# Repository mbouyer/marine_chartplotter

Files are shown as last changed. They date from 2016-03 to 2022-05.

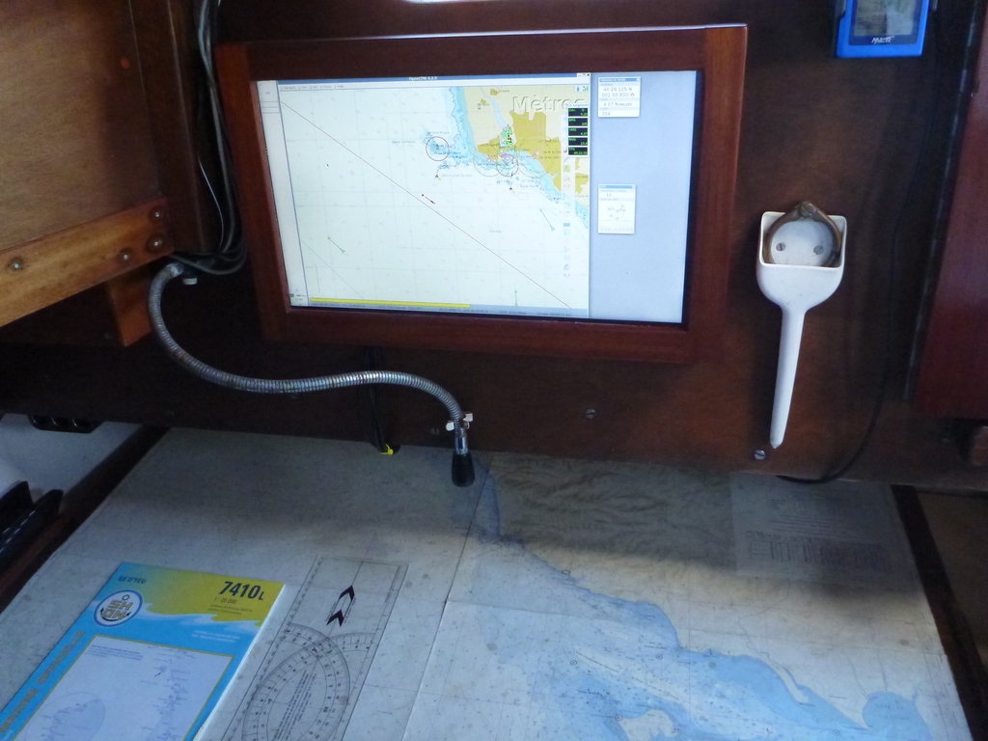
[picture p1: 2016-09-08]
hardware/images/chartplotter.jpg

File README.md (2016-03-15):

Hardware and software for an opencpn-based chartplotter
The kardware has been designed with kicad 4.0.x
The chartplotter is built around a A20-based single-board computer
from Olimex (https://www.olimex.com/Products/OLinuXino/A20/A20-OLinuXIno-LIME2/)
and a 15" TFT full HD display also from Olimex
(https://www.olimex.com/Products/OLinuXino/LCD/LCD-OLinuXino-15.6FHD)

The hardware consist of 4 boards
- a breakout board for the Lime2, also providing power supplies,
  an audio amplifier, RS422 and CAN interfaces, and a I2C connection to
  a PIC18 for power management and TOD clock.
- a board holding buttons
- a board holding a GPS module
- a board for connections to other electronic equipements (VHF, sensors, ...)
  via a single flat cable.

for more details see the wiki: https://github.com/mbouyer/marine_chartplotter/wiki

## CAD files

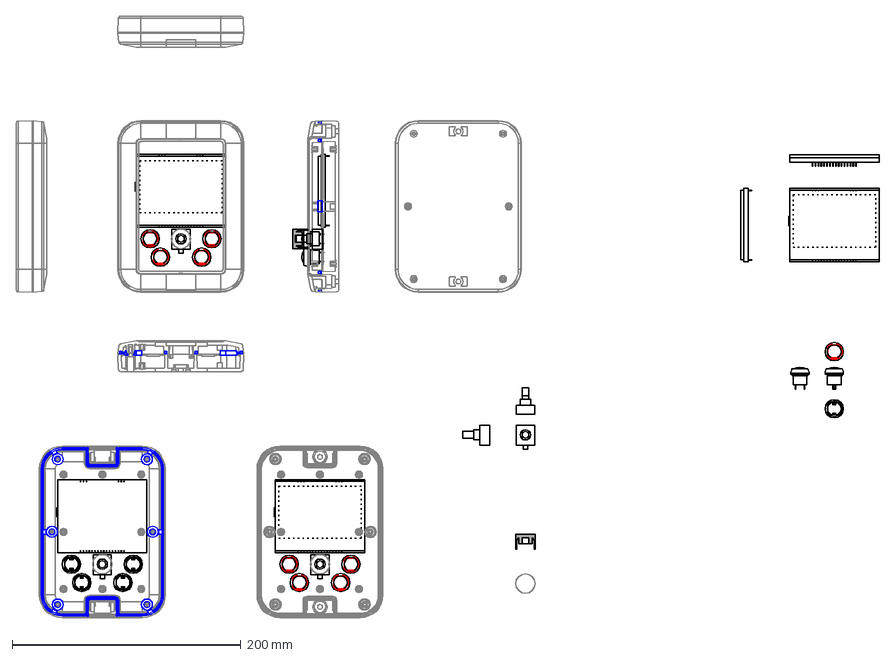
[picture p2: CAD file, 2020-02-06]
hardware/CAD/wp11+dogxl160-codeur.dxf
754.1 x 525.5 mm

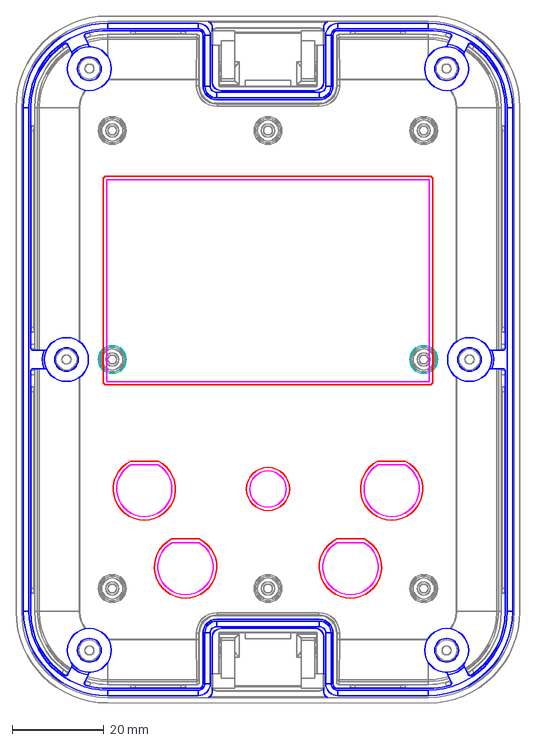
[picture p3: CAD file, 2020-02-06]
hardware/CAD/panel-cut.dxf
110.0 x 150.0 mm

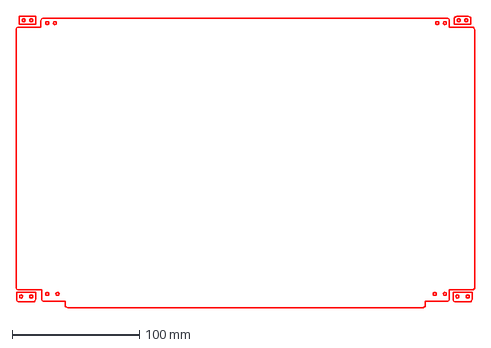
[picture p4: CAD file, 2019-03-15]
hardware/CAD/LCD_screen.dxf
360.5 x 229.0 mm

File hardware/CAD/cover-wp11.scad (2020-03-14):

$fn=100;
longueur = 150.5;
largeur = 110.5;
hauteur = 42;
rayon = 20;
base_ep = 1.5;
murs_ep = 1.5;

longueur_e = longueur+murs_ep*2;
largeur_e = largeur+murs_ep*2;
rayon_e = rayon + murs_ep;

longueur_c = longueur / 2 - rayon;
largeur_c = largeur / 2 - rayon;

conge = murs_ep * 2;

module quart_tore() {
	rotate_extrude(angle = 90, convexity=10) translate([rayon, 0, 0])
	    difference() {
		translate([-conge/2, conge/2, 0]) square([conge, conge], center=true);
		translate([-conge, conge, 0]) circle(r=conge, $fn=500);
	    };
}

module quart_rond(l) {
	difference() {
		translate([-conge/2, -conge/2, 0]) cube([conge, conge, l], center=true);
		translate([-conge, -conge, 0]) cylinder(r=conge, h=l, center=true, $fn=500);
	}
}

module quart_tube() {
	intersection() {
		difference() {
			cylinder(r = rayon_e, h = hauteur, center=true, $fn = 500);
			cylinder(r = rayon - 0.001, h = hauteur, center=true, $fn = 500);
		};
		translate([rayon_e/2, rayon_e/2, 0]) cube([rayon_e, rayon_e, hauteur], center=true);
	};
}

module base () {
	union() {
		difference() {
			cube([longueur_e, largeur_e, base_ep], center = true);
			translate([longueur/2, largeur/2, 0]) cube([rayon*2, rayon*2, base_ep], center = true);
			translate([-longueur/2, largeur/2, 0]) cube([rayon*2, rayon*2, base_ep], center = true);
			translate([-longueur/2, -largeur/2, 0]) cube([rayon*2, rayon*2, base_ep], center = true);
			translate([longueur/2, -largeur/2, 0]) cube([rayon*2, rayon*2, base_ep], center = true);
		} ;
		translate([longueur_c, largeur_c, 0]) cylinder(r = (rayon+murs_ep), h = base_ep, center = true, $fn = 500);
		translate([-longueur_c, largeur_c, 0]) cylinder(r = (rayon+murs_ep), h = base_ep, center = true, $fn = 500);
		translate([-longueur_c, -largeur_c, 0]) cylinder(r = (rayon+murs_ep), h = base_ep, center = true, $fn = 500);
		translate([longueur_c, -largeur_c, 0]) cylinder(r = (rayon+murs_ep), h = base_ep, center = true, $fn = 500);

	};
}

module murs() {
	translate([0,0,base_ep/2 + hauteur/2]) union() {
		translate([(longueur+murs_ep)/2, 0, 0]) cube([murs_ep + 0.0001, largeur-rayon*2, hauteur], center = true);
		translate([-(longueur+murs_ep)/2, 0, 0]) cube([murs_ep + 0.0001, largeur-rayon*2, hauteur], center = true);
		translate([0, (largeur+murs_ep)/2, 0]) cube([longueur-rayon*2, murs_ep + 0.0001, hauteur], center = true);
		translate([0, -(largeur+murs_ep)/2, 0]) cube([longueur-rayon*2, murs_ep + 0.0001, hauteur], center = true);
		translate([longueur_c, largeur_c, 0]) quart_tube();
		translate([-longueur_c, largeur_c, 0]) rotate([0,0,90]) quart_tube();
		translate([-longueur_c, -largeur_c, 0]) rotate([0,0,180]) quart_tube();
		translate([longueur_c, -largeur_c, 0]) rotate([0,0,-90]) quart_tube();
	};
}

module conges() {
	translate([0,0,base_ep/2]) union() {
		translate([longueur/2, 0, 0]) rotate([90,90,0]) quart_rond(largeur-rayon*2);
		translate([-longueur/2, 0, 0]) rotate([-90,90,0]) quart_rond(largeur-rayon*2);
		translate([0, largeur/2, 0]) rotate([0,90,0]) quart_rond(longueur-rayon*2);
		translate([0, -largeur/2, 0]) rotate([90,90,-90]) quart_rond(longueur-rayon*2);
		translate([longueur_c, largeur_c, 0]) quart_tore();
		translate([-longueur_c, largeur_c, 0]) rotate([0,0,90]) quart_tore();
		translate([-longueur_c, -largeur_c, 0]) rotate([0,0,180]) quart_tore();
		translate([longueur_c, -largeur_c, 0]) rotate([0,0,-90]) quart_tore();
	};
}

module all() {
	union() {
		base();
		murs();
		conges();

	};
}

all();

// difference() {
// 	all ();
// 	cube([longueur+10, largeur+10, (hauteur-5) * 2], center=true);
// }
// projection(cut=true) translate([0,0, -(base_ep+conge+0.1)]) all();
// projection(cut=true) rotate([90, 0, 0]) all();

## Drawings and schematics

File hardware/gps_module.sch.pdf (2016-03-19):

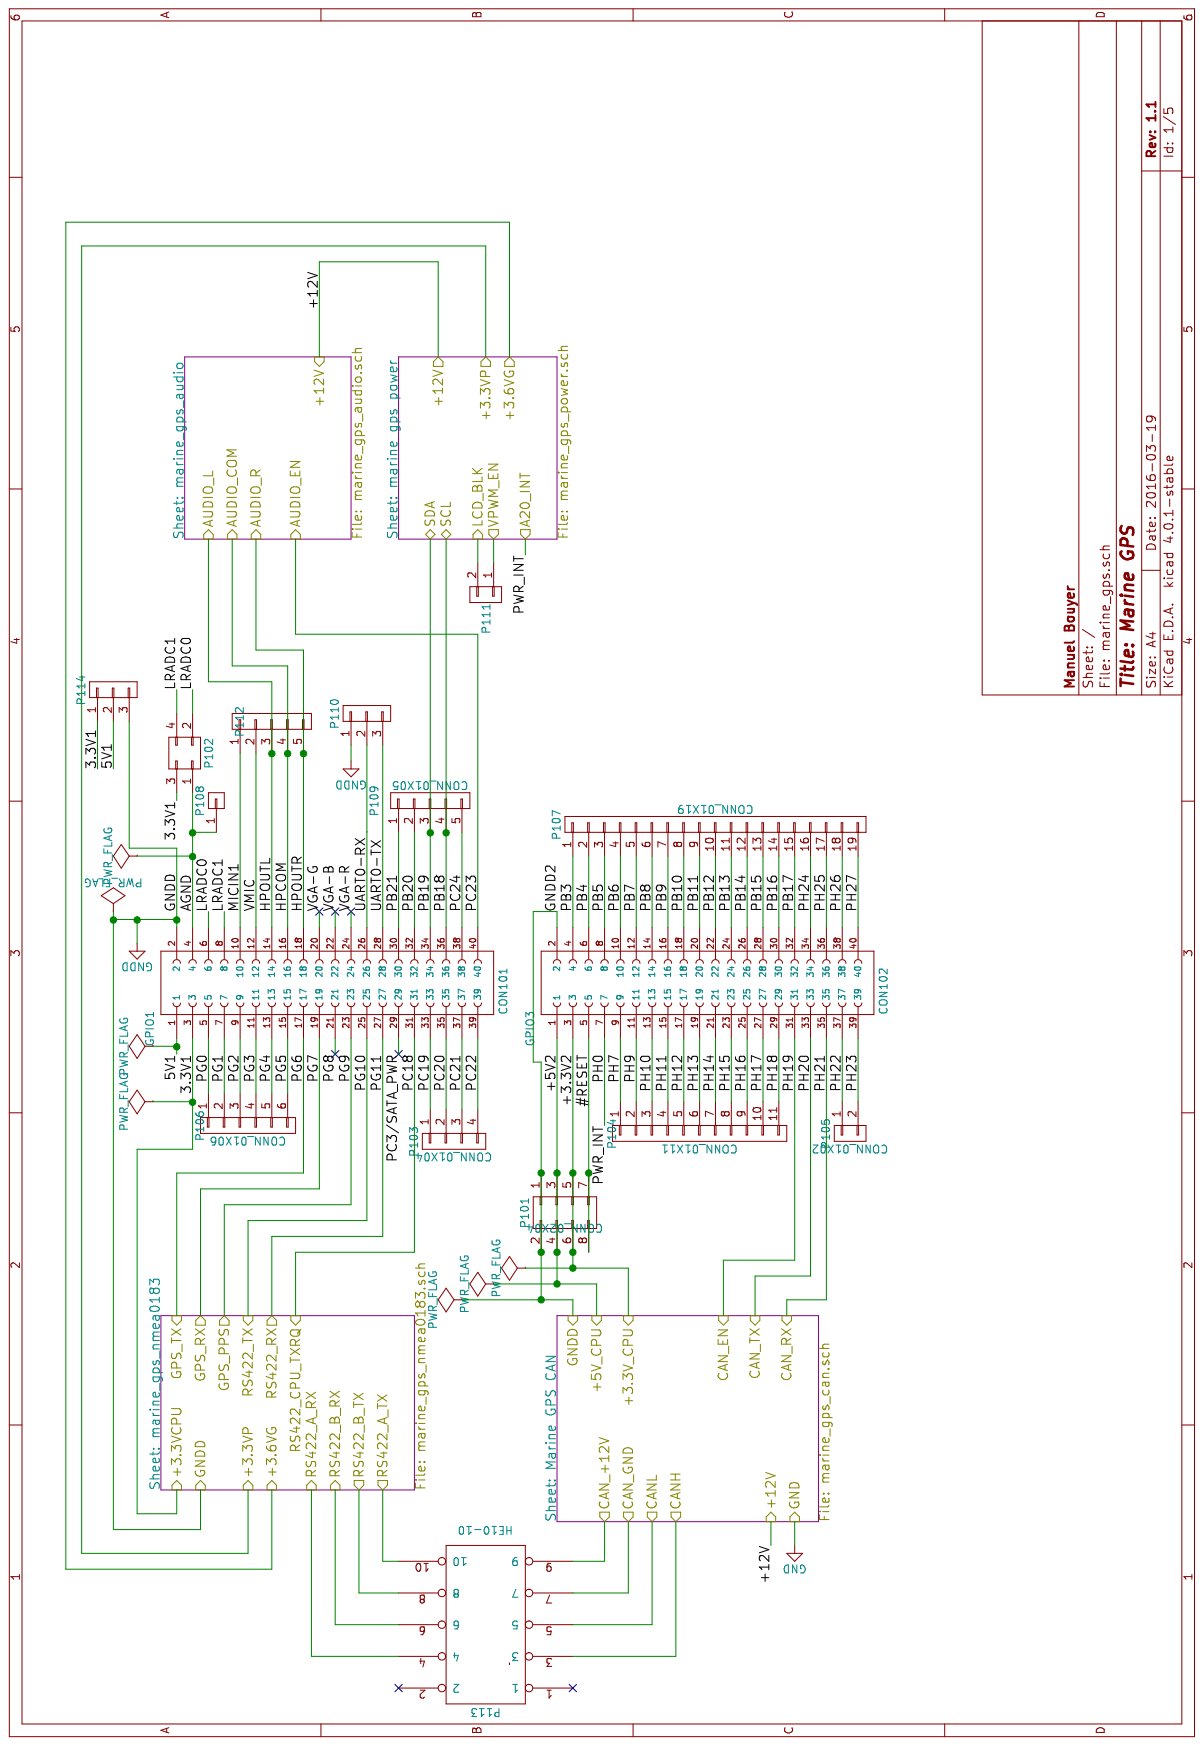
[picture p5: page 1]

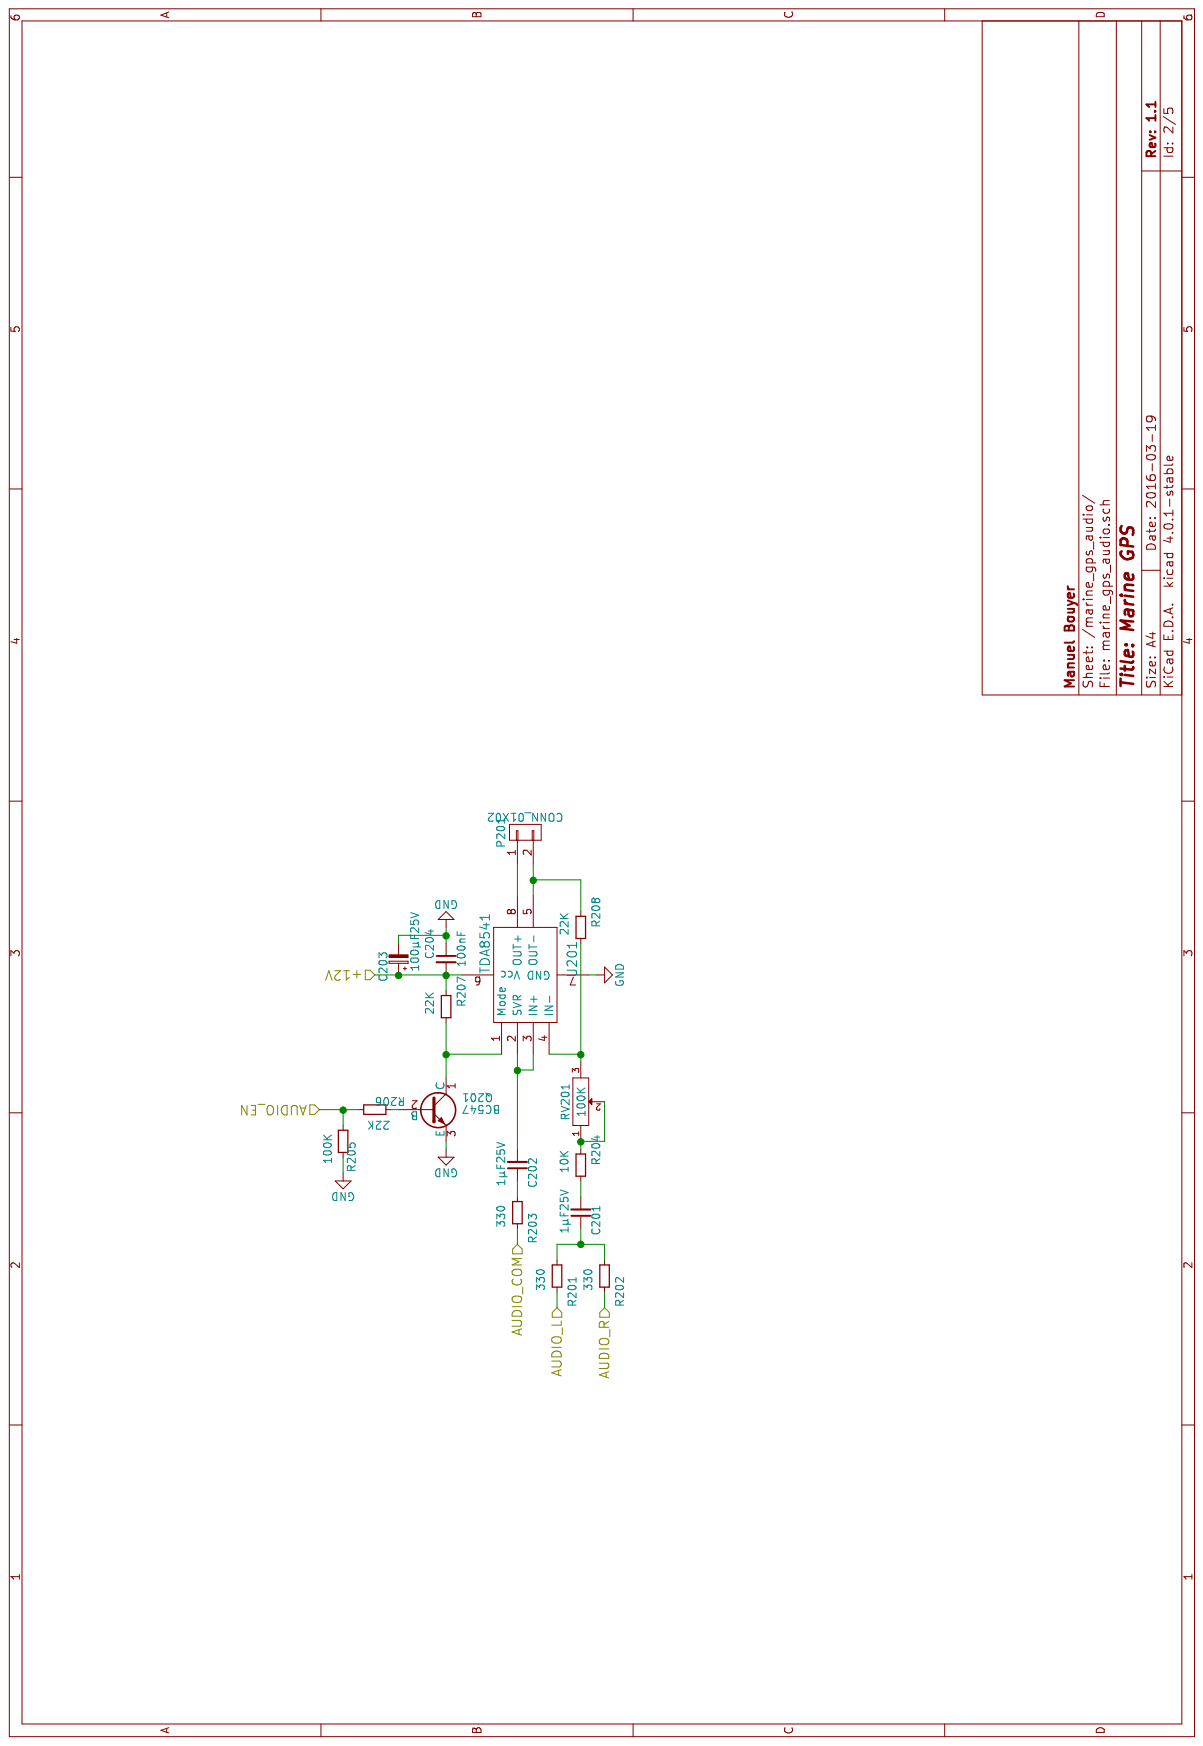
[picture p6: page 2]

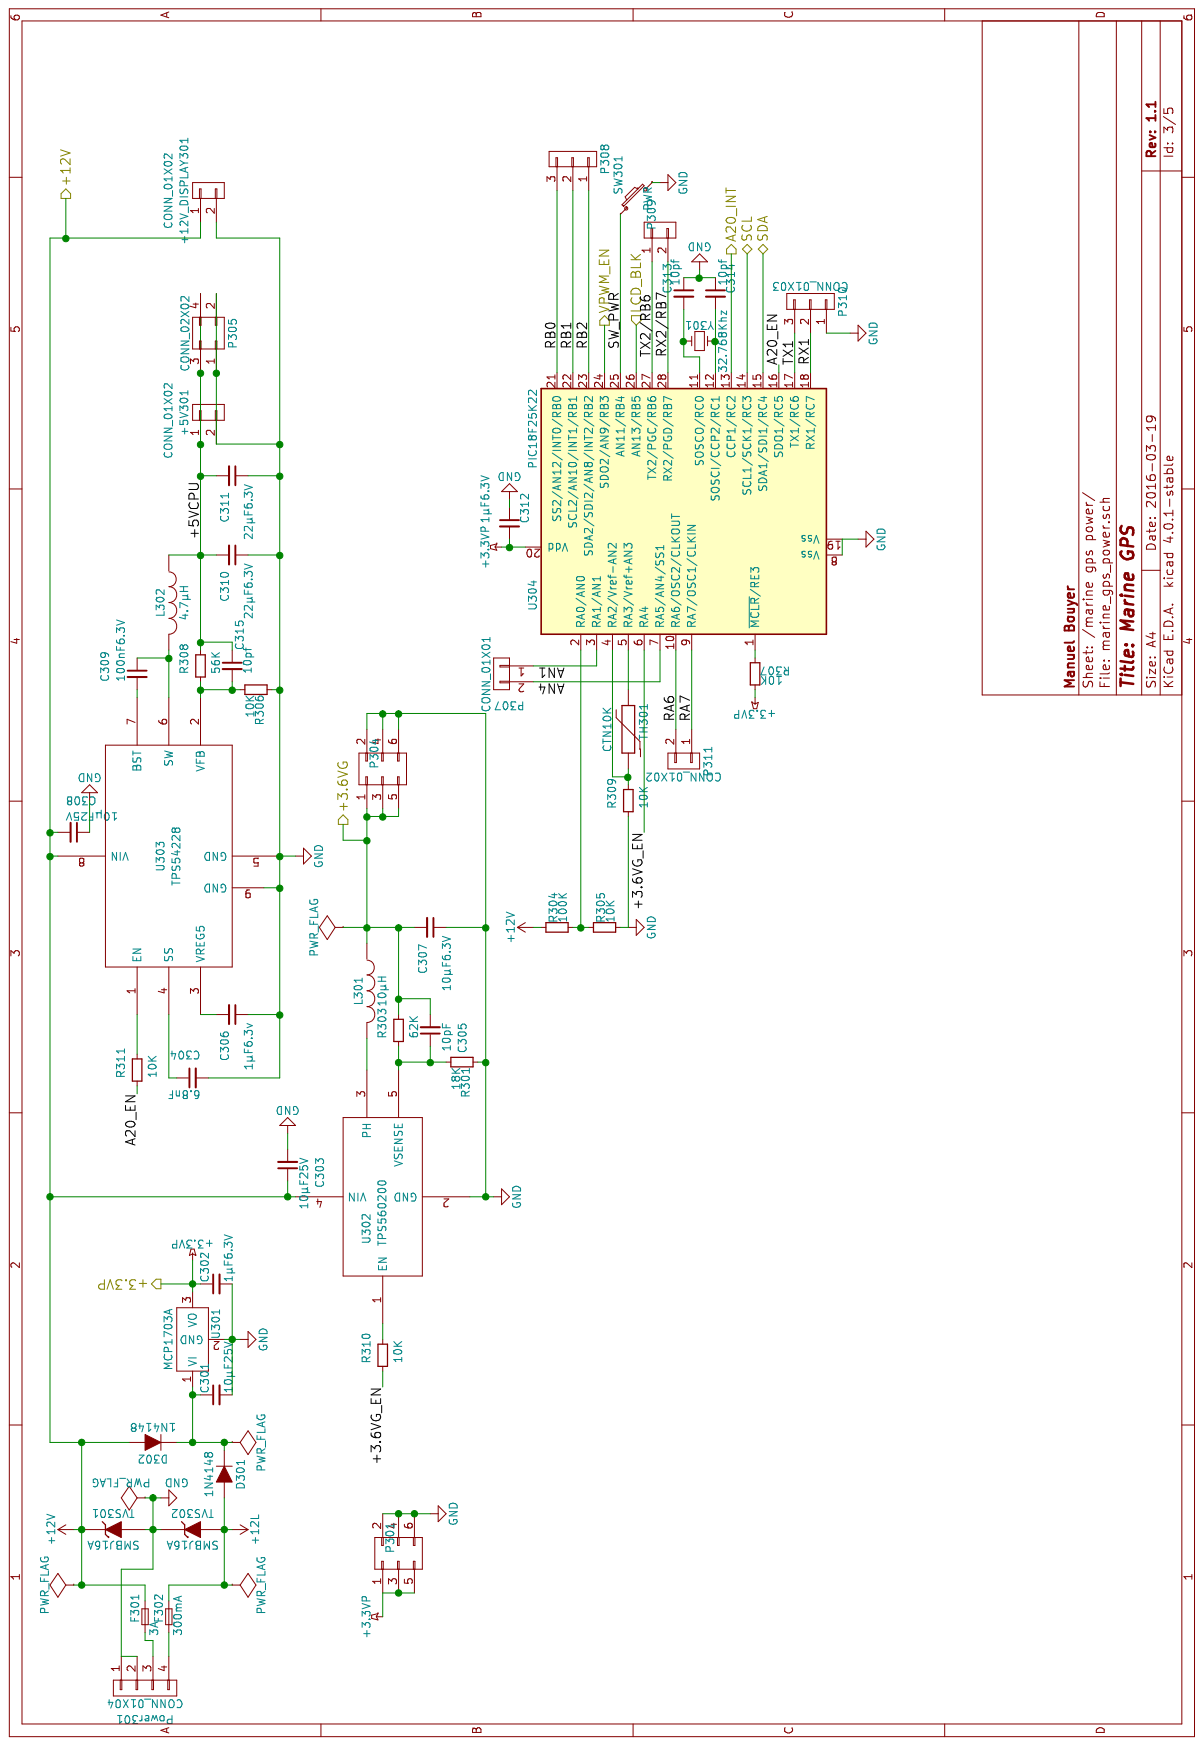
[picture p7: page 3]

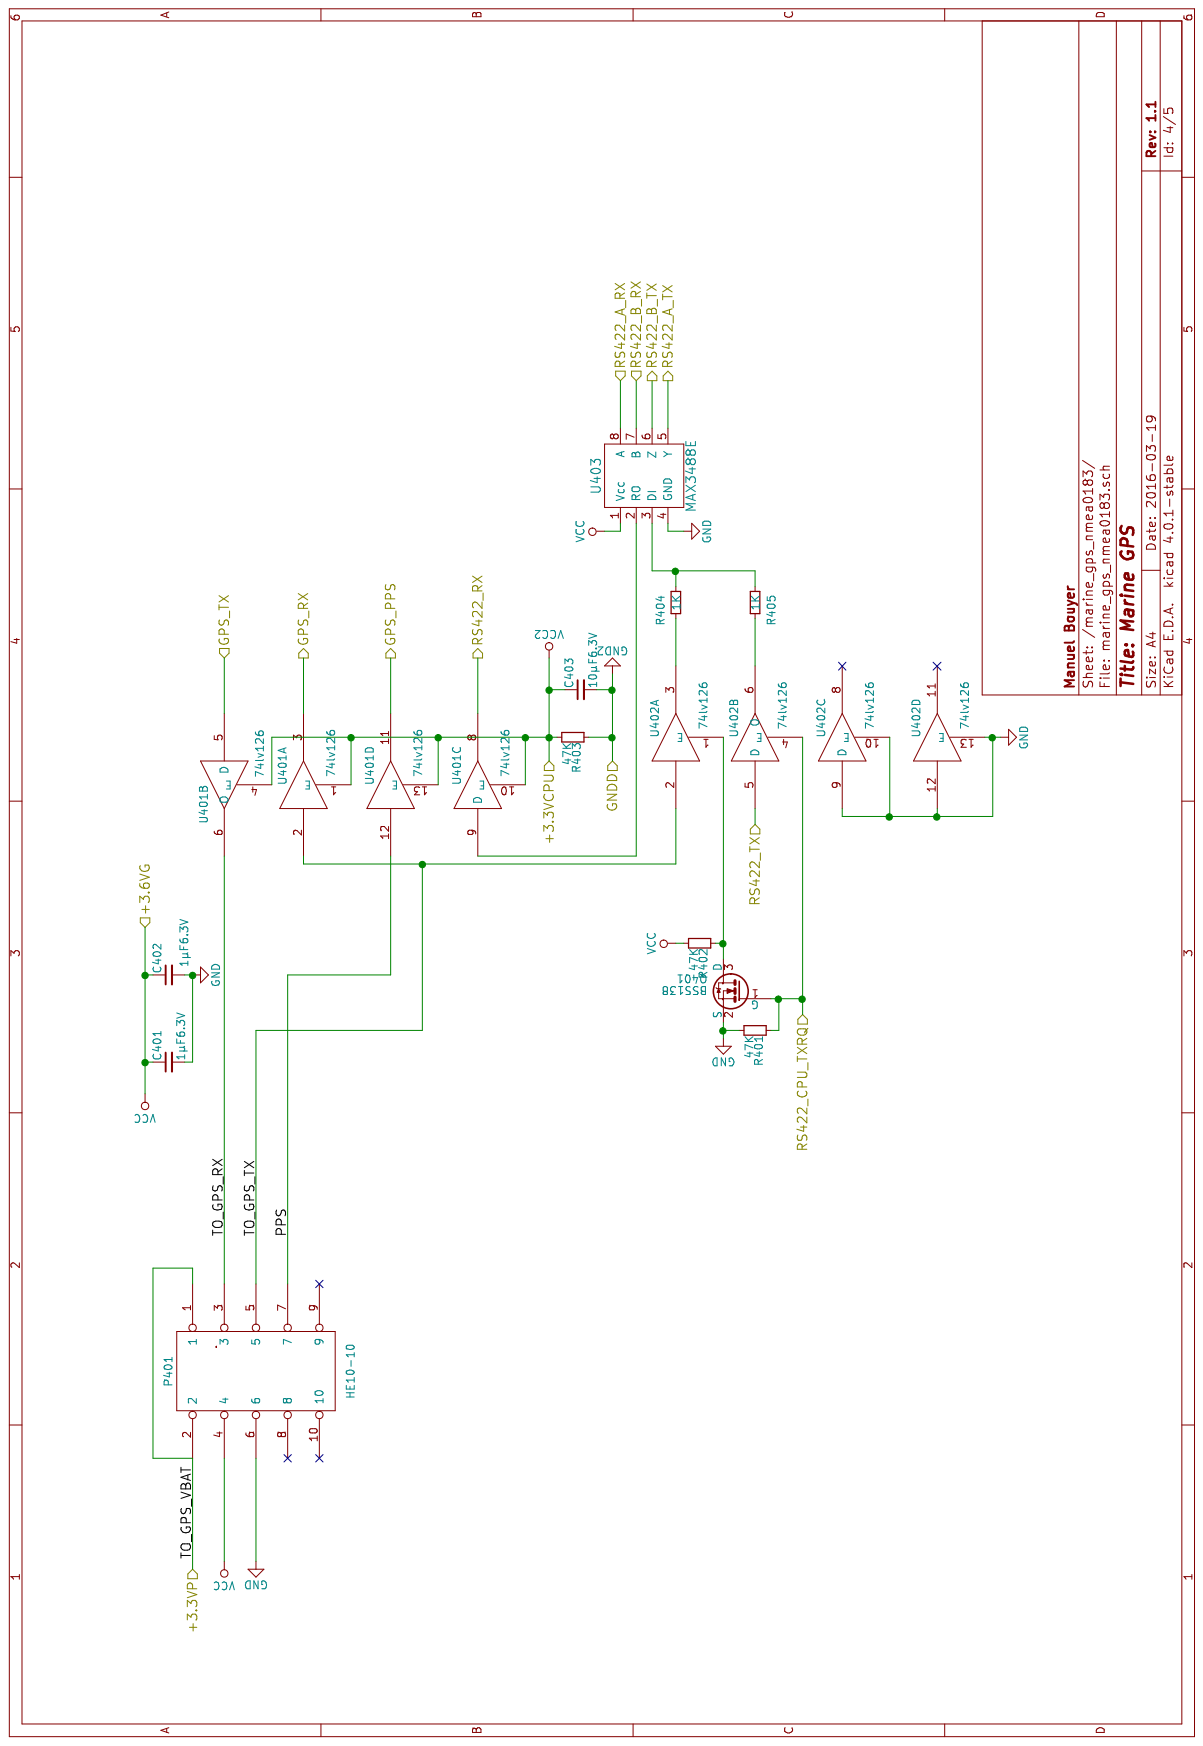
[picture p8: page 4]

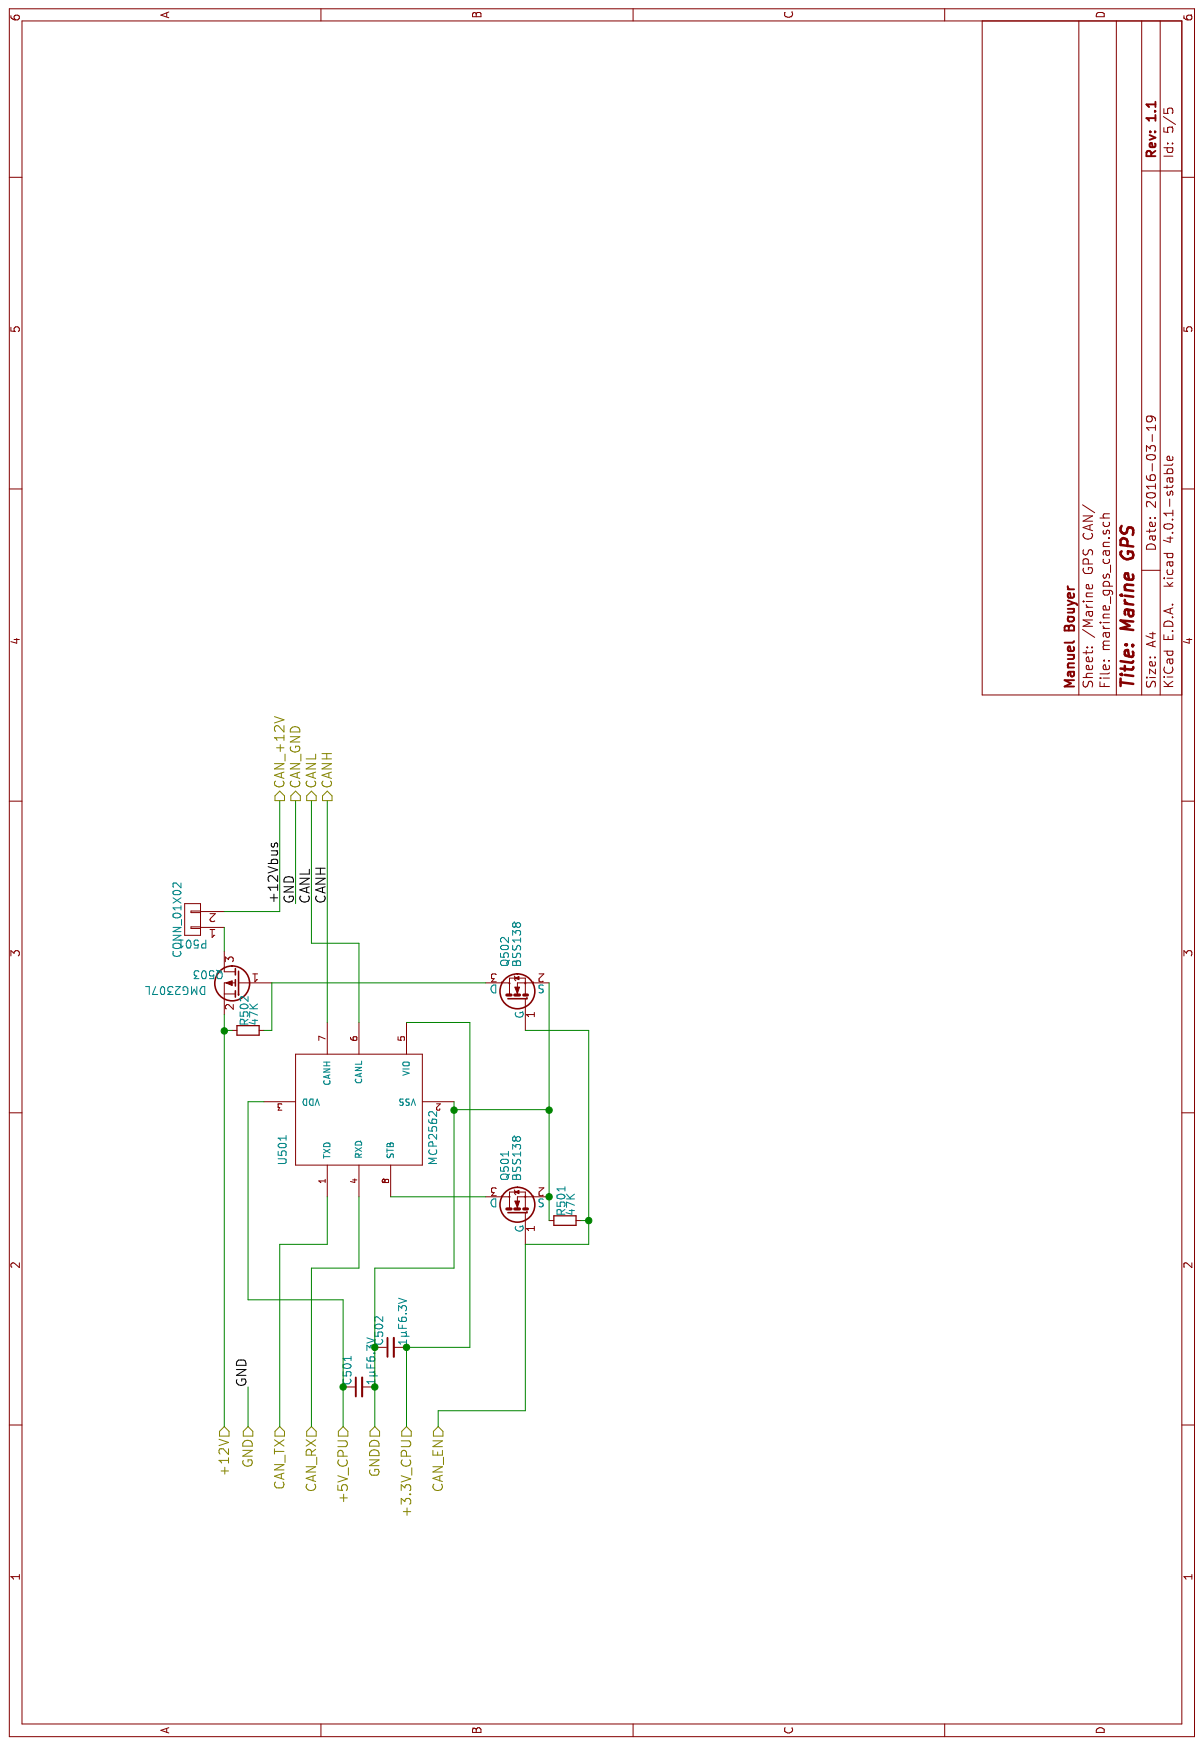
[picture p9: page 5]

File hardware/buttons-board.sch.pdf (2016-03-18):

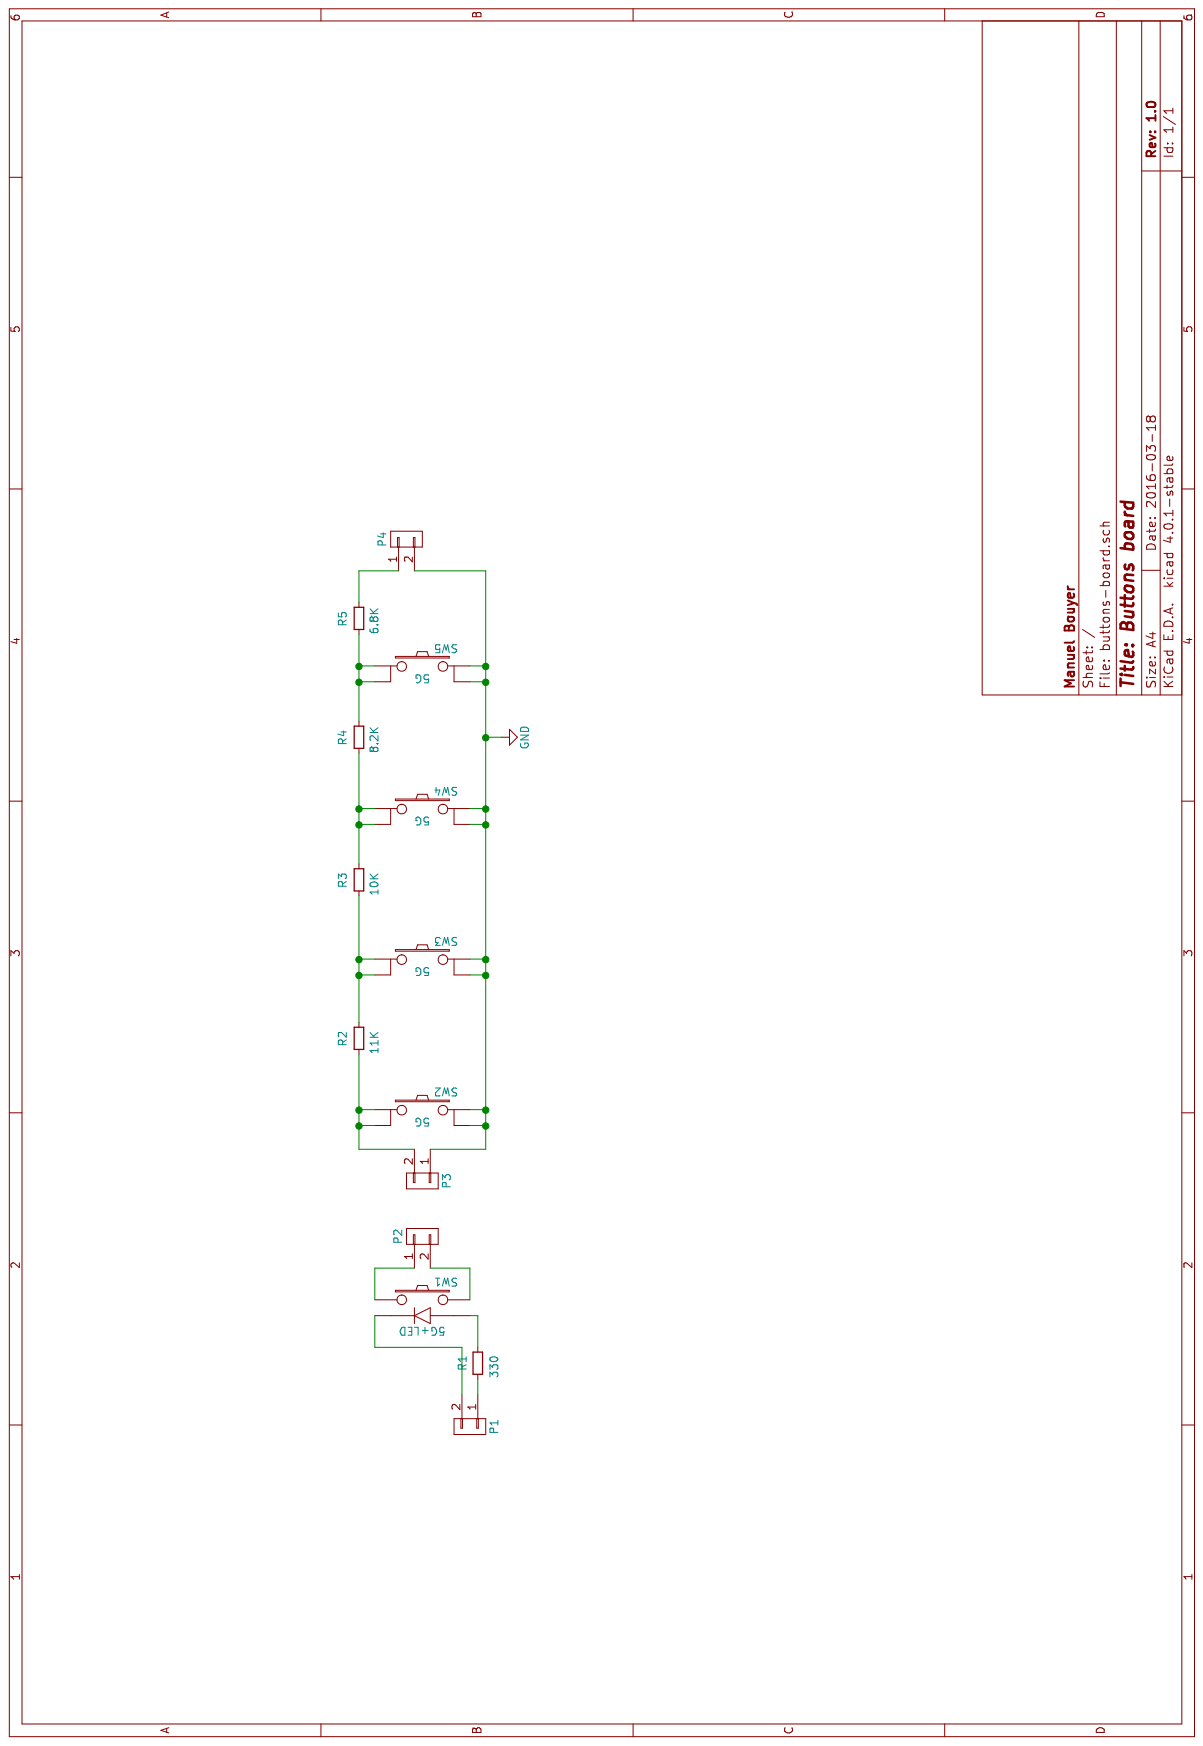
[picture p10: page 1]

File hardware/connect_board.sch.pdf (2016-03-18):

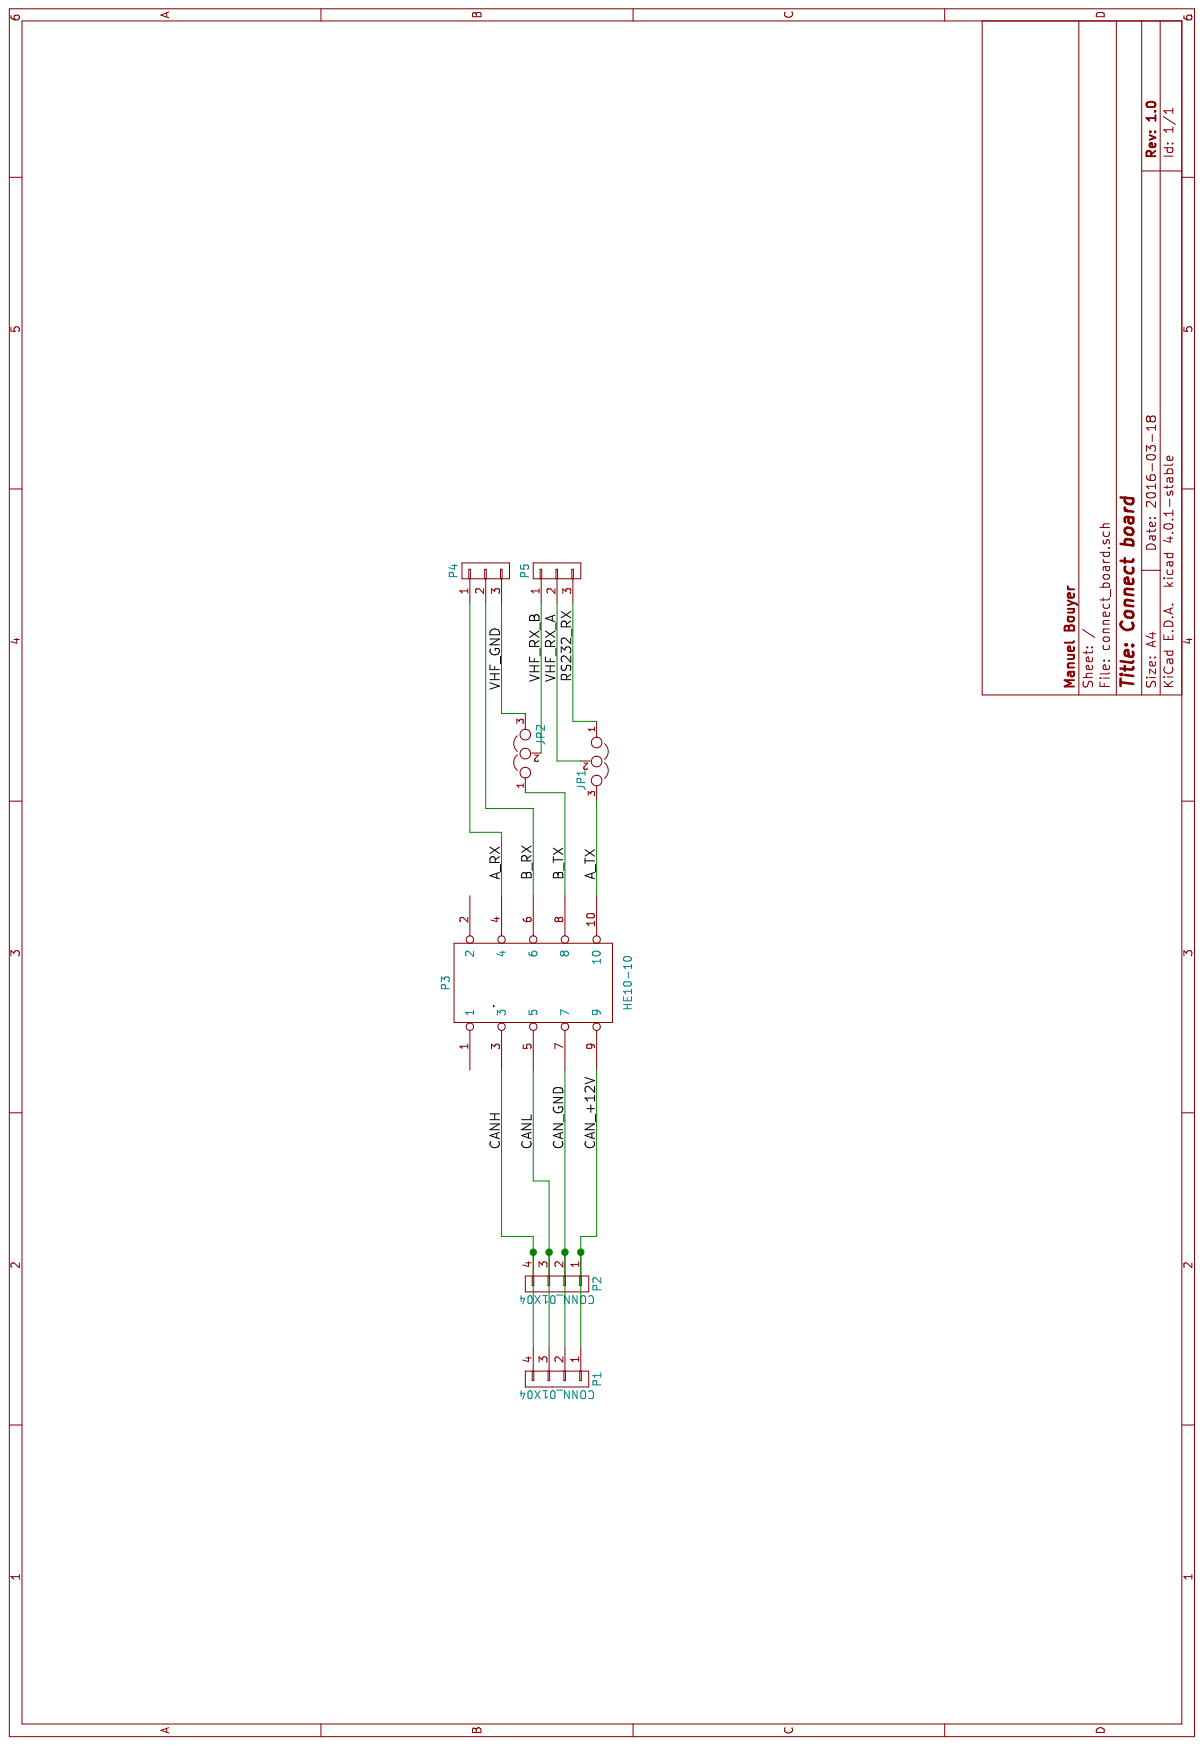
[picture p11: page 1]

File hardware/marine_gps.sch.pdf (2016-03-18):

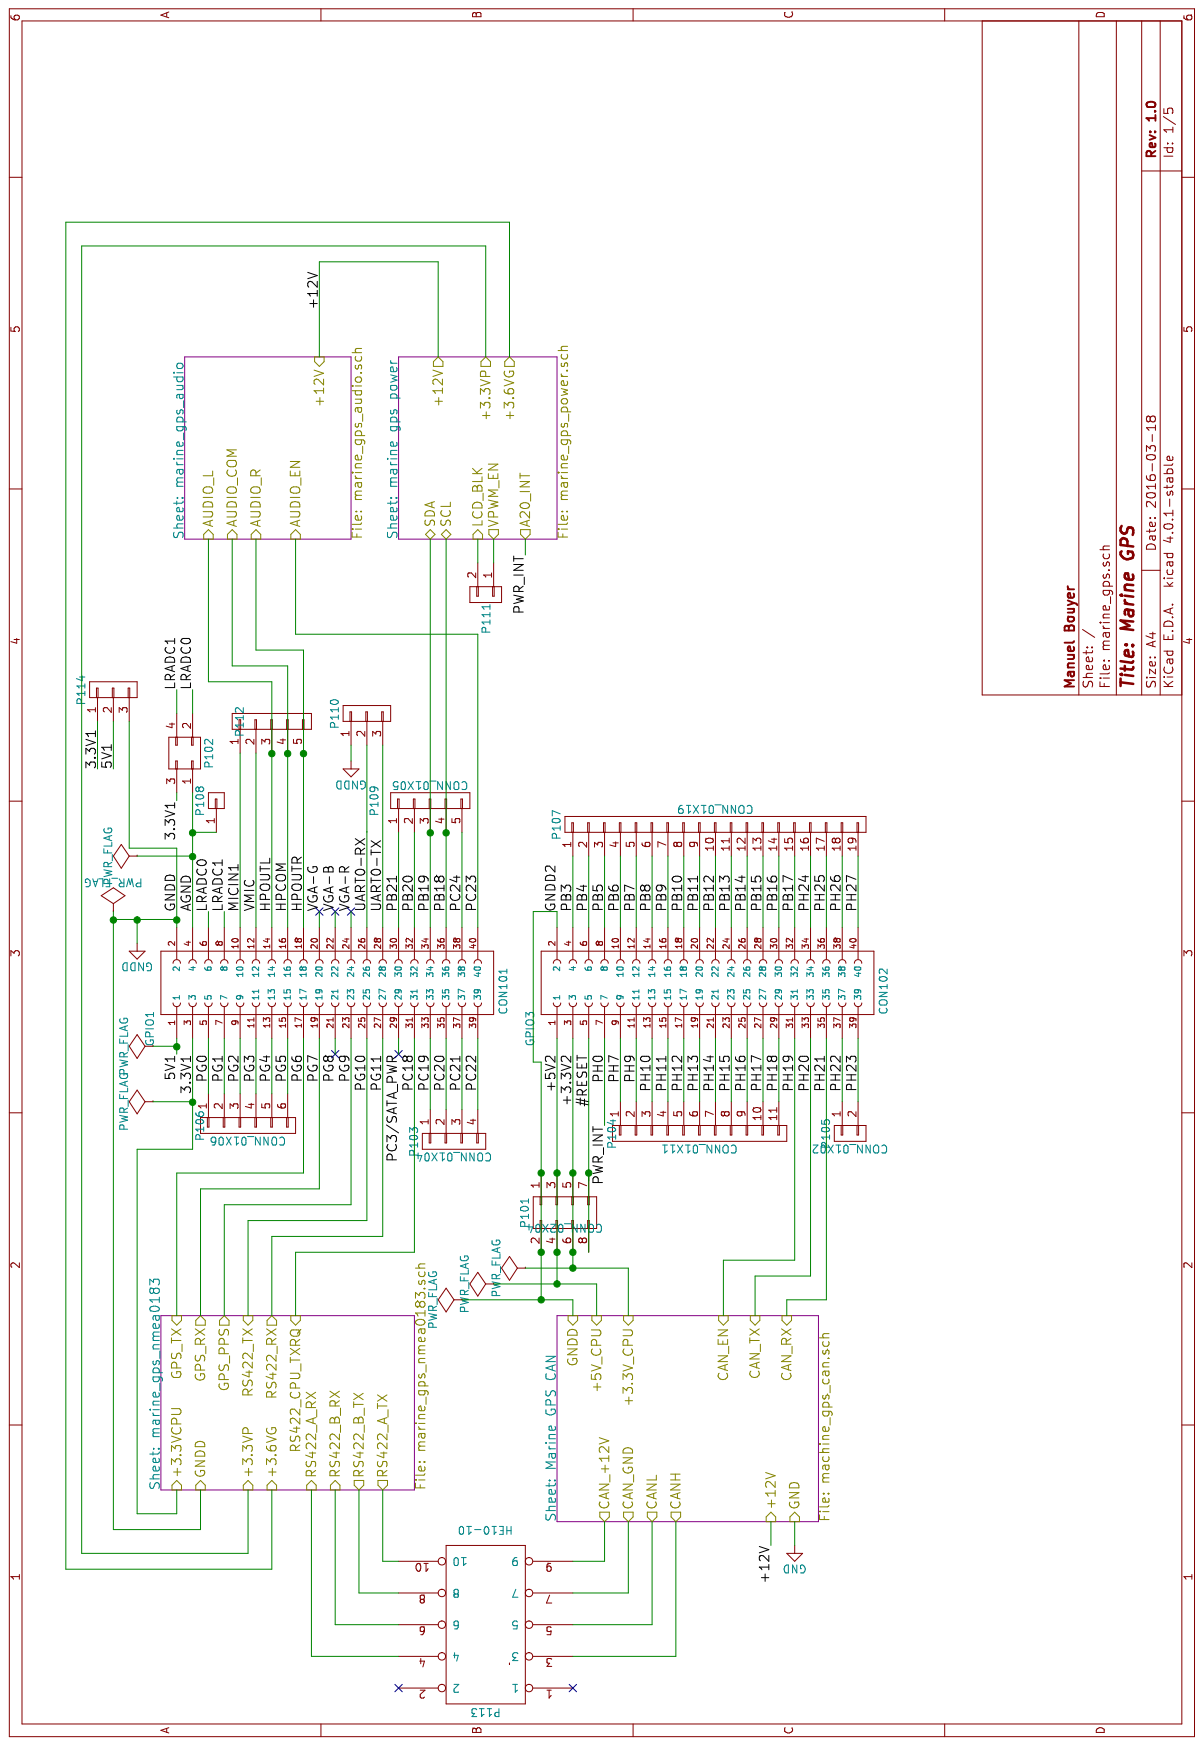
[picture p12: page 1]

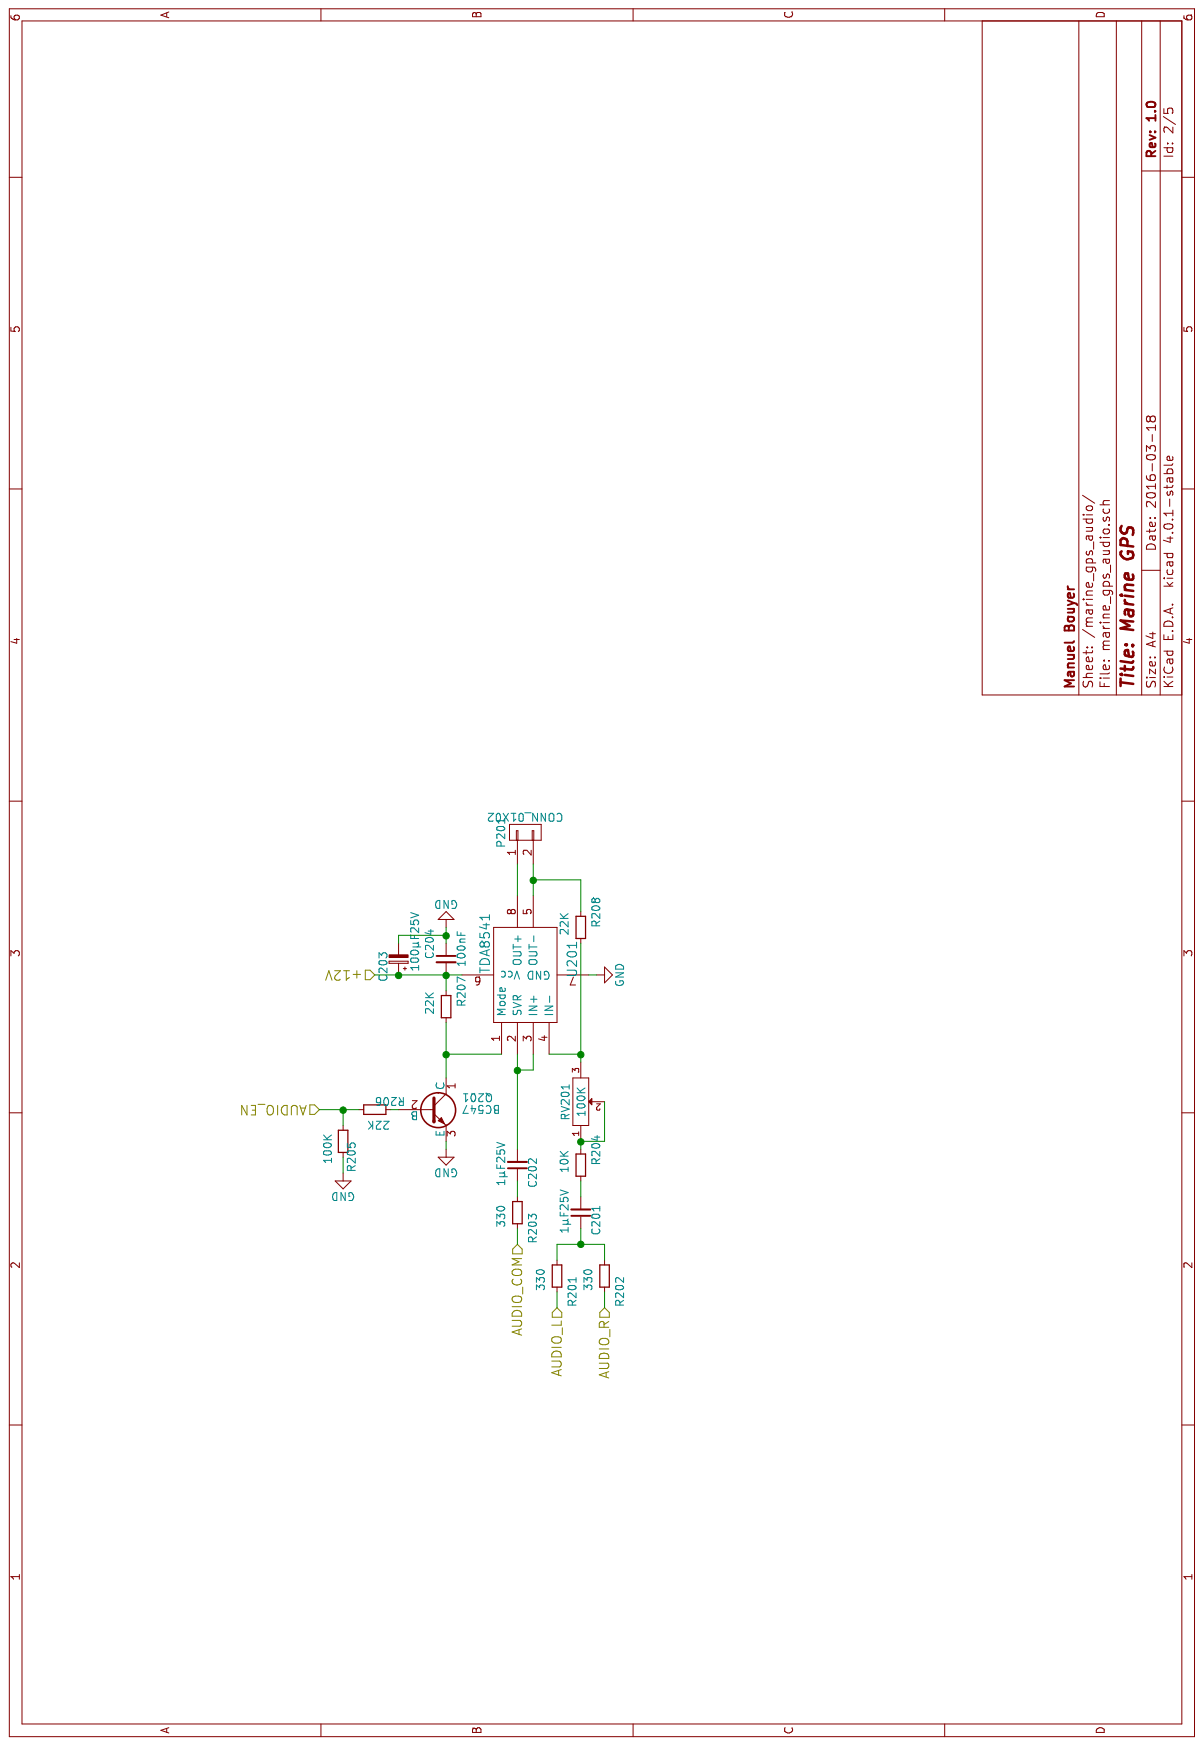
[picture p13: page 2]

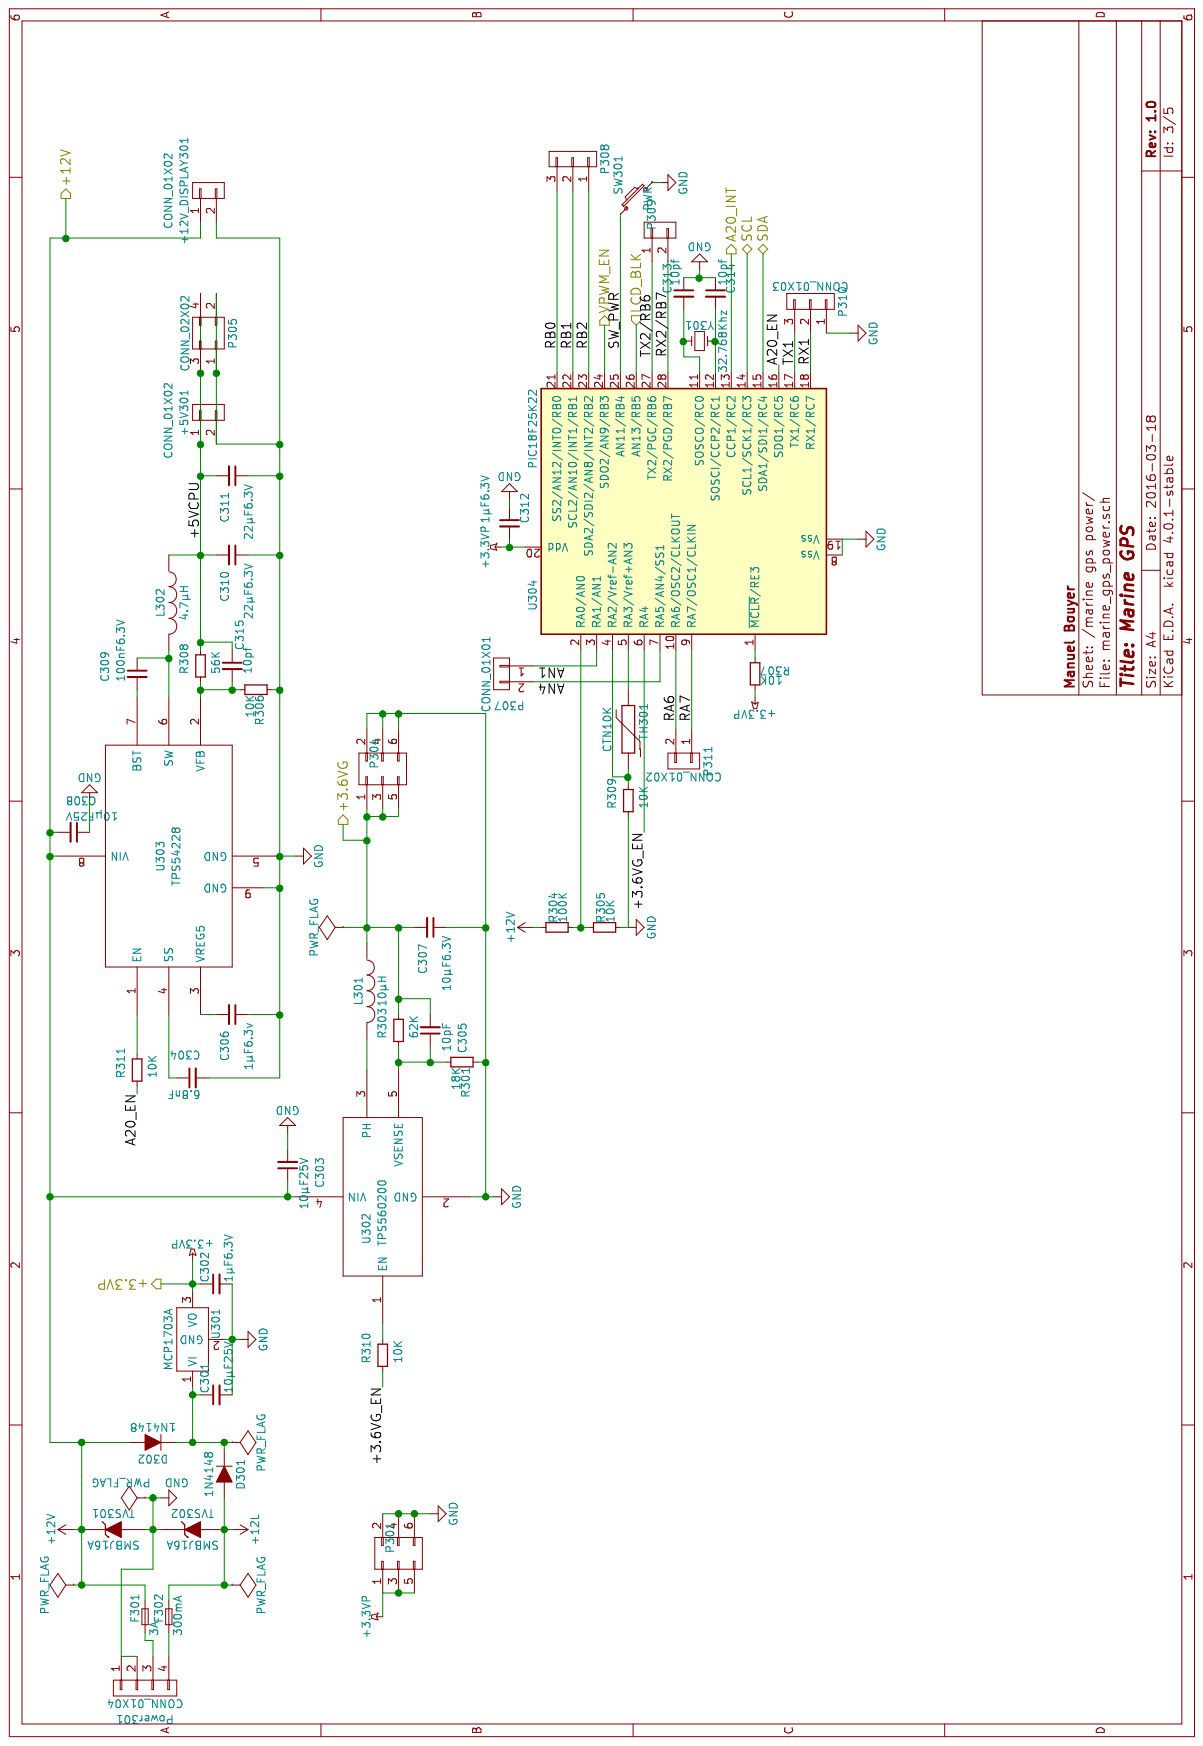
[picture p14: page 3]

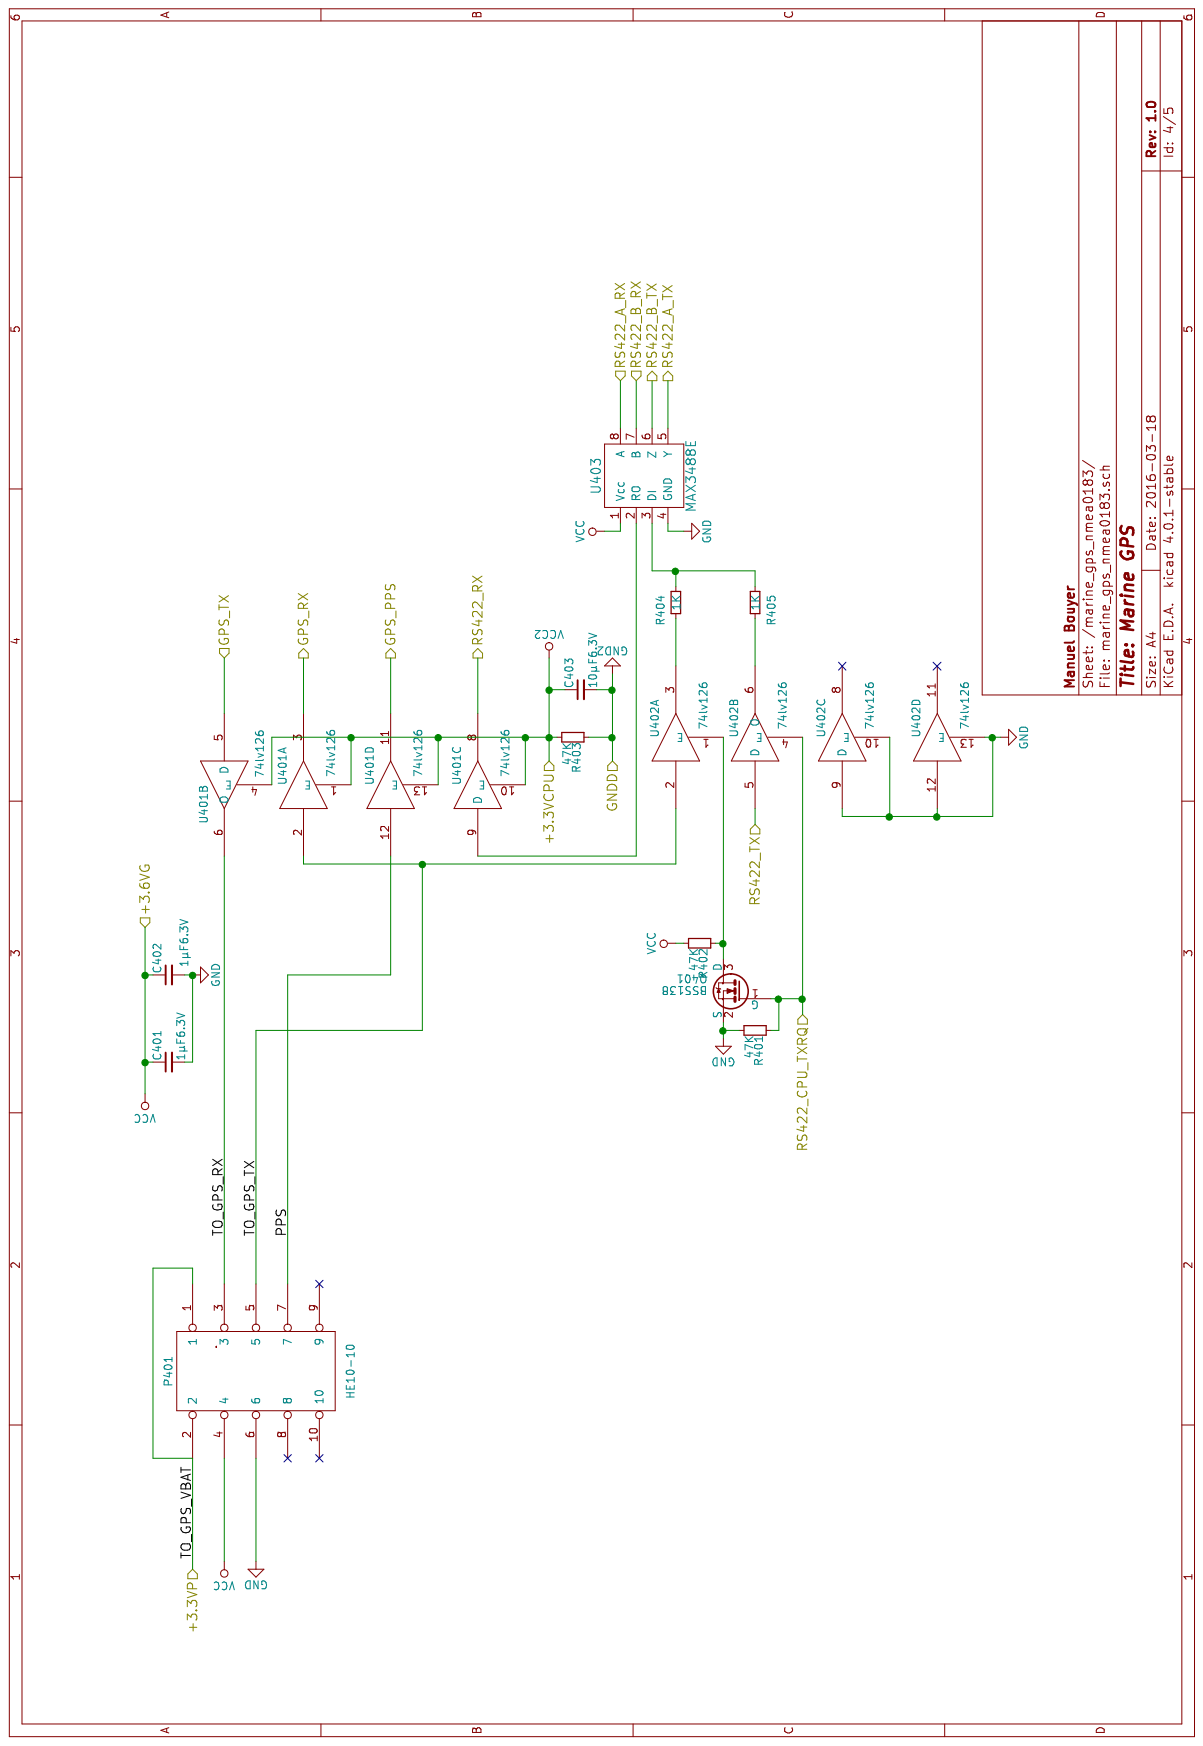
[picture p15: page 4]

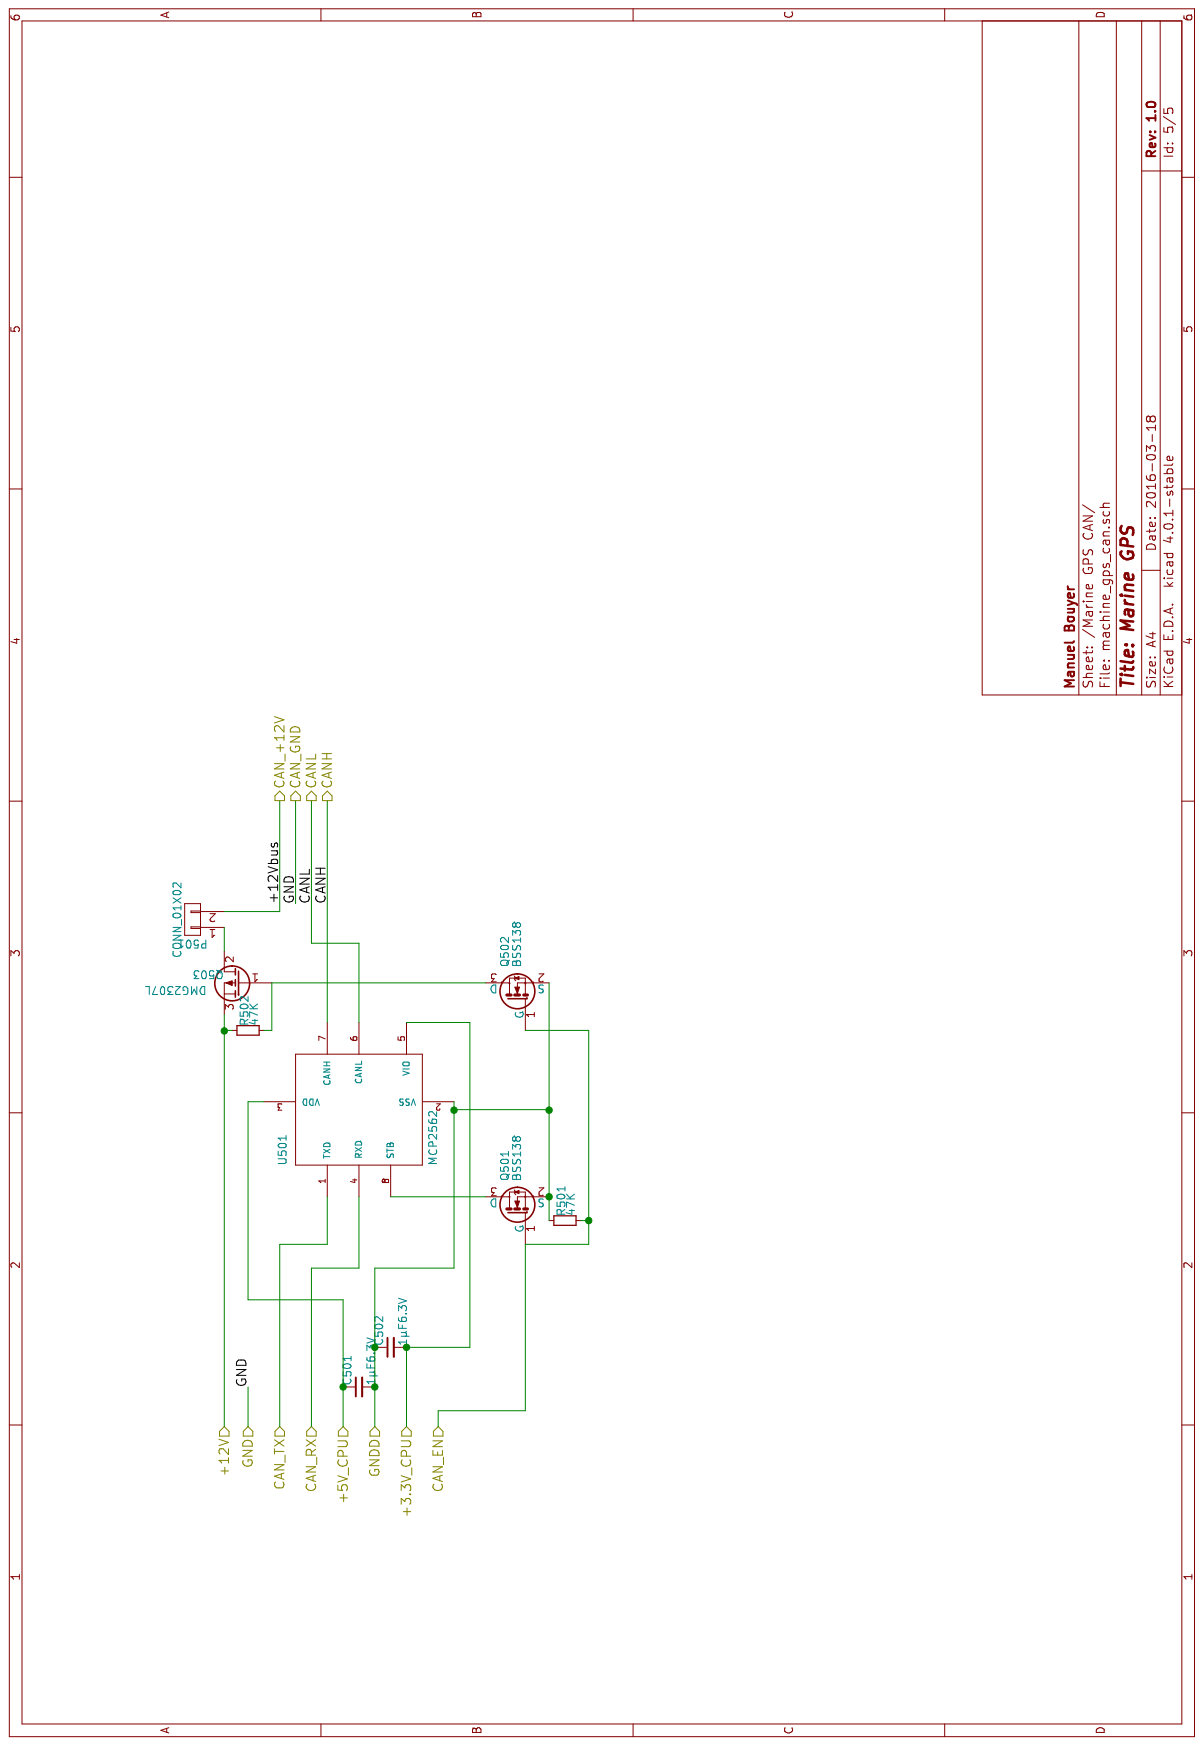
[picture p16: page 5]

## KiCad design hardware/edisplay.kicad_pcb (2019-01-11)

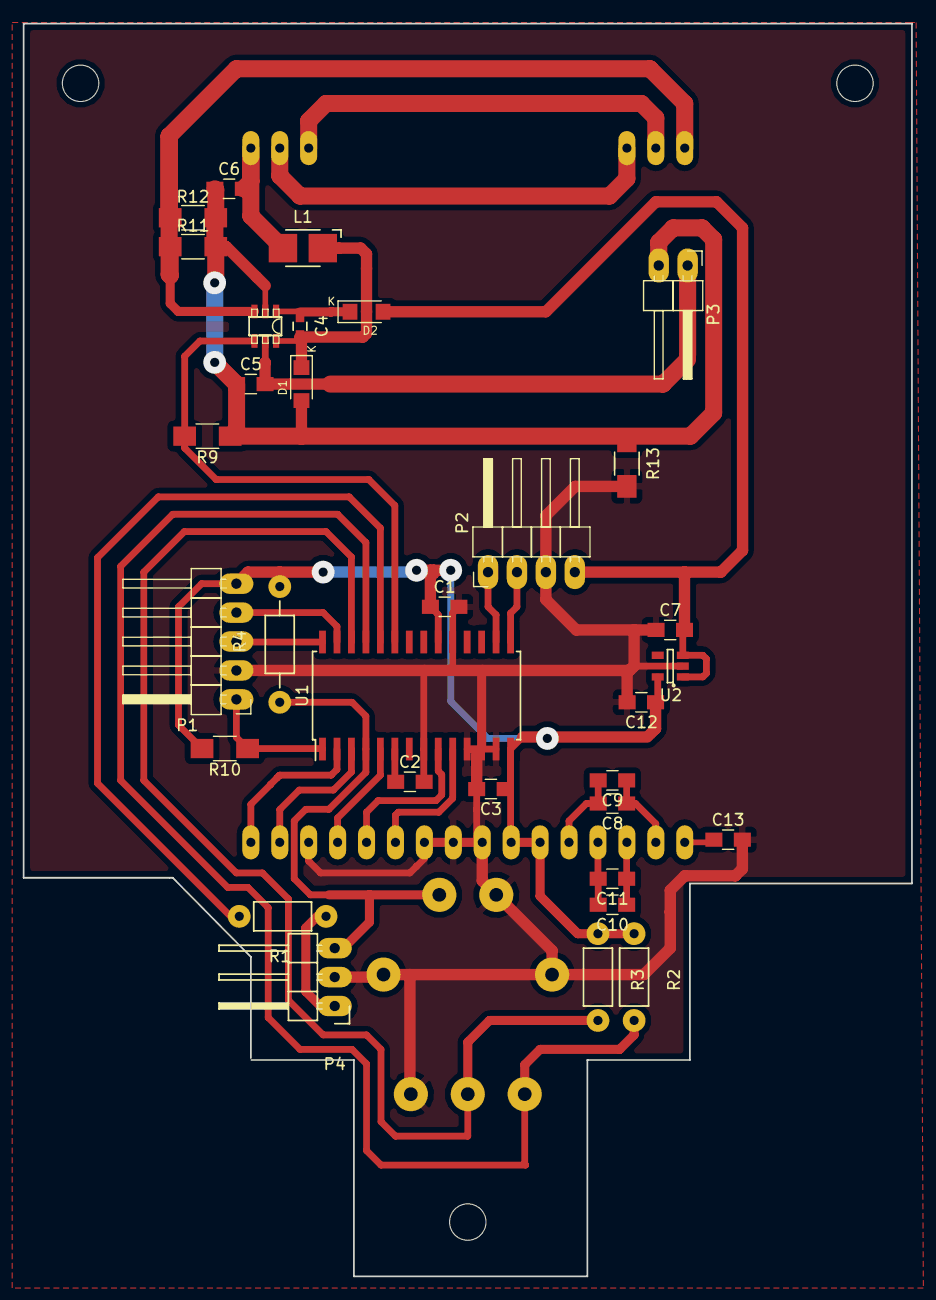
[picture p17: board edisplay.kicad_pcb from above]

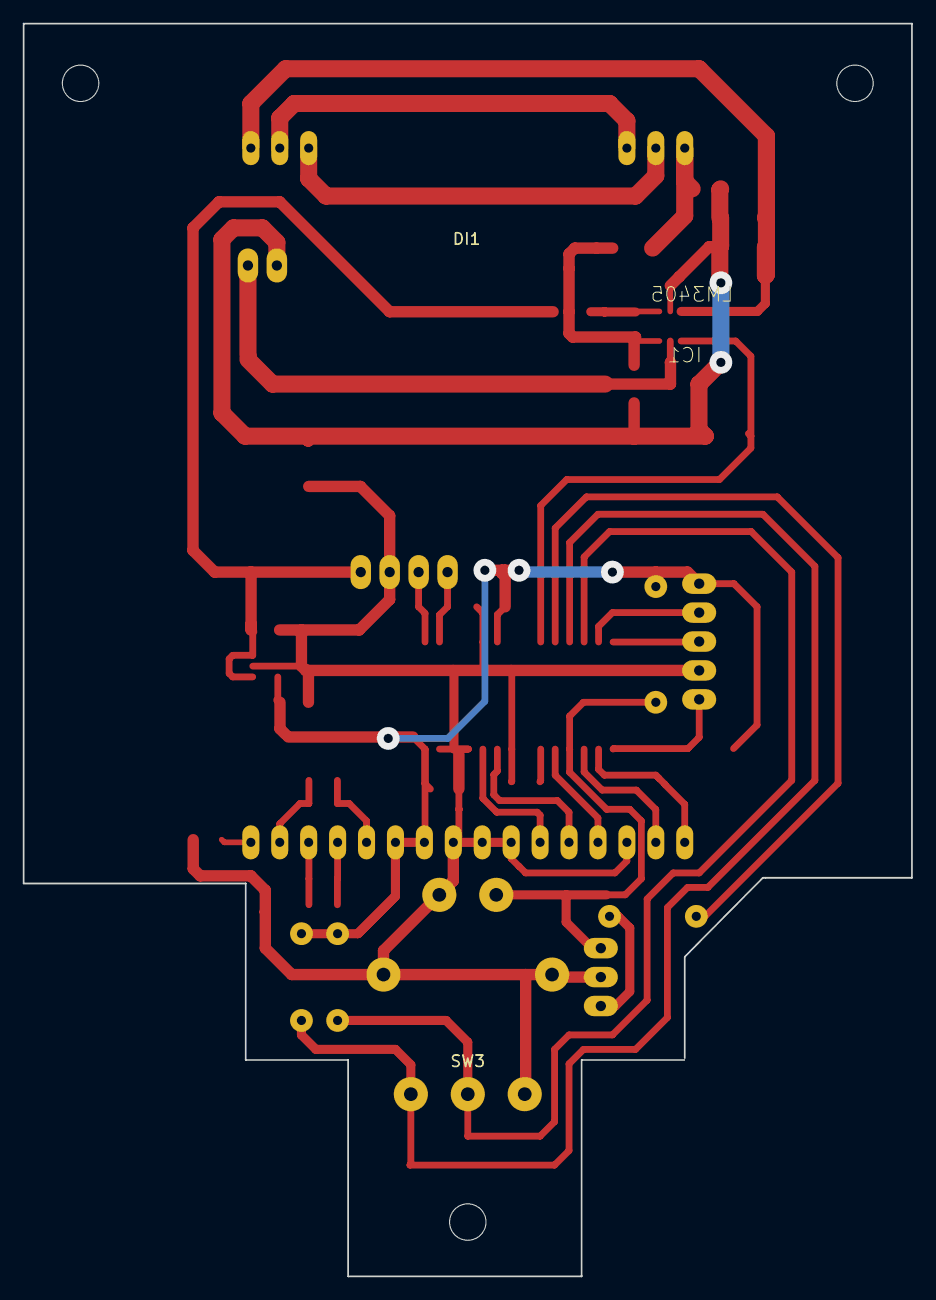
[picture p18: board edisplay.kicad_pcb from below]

Board: 2 copper layers, 78.0 x 110.0 mm, 34 parts (2 on the bottom side), 33 nets.

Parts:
C1, C3, C5, C6, C7, C8, C9, C10, C11, C12, C13: 1µF; C_0805_HandSoldering
C2: 10µF; C_0805_HandSoldering
C4: 0.1µF; C_0603_HandSoldering
D1, D2: SL02; DO-219AB
DI1: EADOGXL160-7
IC1: LM3405; texas-local-SOT23-06
L1: 68µH; Inductor_1212
P1: CONN_01X05; Pin_Header_Angled_1x05_Pitch2.54mm
P2: CONN_01X04; Pin_Header_Angled_1x04_Pitch2.54mm
P3: CONN_01X02; Pin_Header_Angled_1x02_Pitch2.54mm
P4: CONN_01X03; Pin_Header_Angled_1x03
R1: 330; Resistor_Horizontal_RM7mm
R2, R3: 10K; Resistor_Horizontal_RM7mm
R4: 10K; Resistor_Horizontal_RM10mm
R9: 10K; R_1206_HandSoldering
R10: 1K; R_1206_HandSoldering
R11, R12: 5.1; R_1206_HandSoldering
R13: 330; R_1206_HandSoldering
SW3: ROTARY_ENCODER_SWITCH; PEC16_S
U1: PIC18F26J53; SOIC-28W_7.5x17.9mm_Pitch1.27mm
U2: LP3990MF; SOT-23-5

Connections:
+3V3: C1.1, C3.1, C12.1, DI1.22, DI1.23, P1.5, R2.1, R3.1, R4.2, R10.2, U1.14, U1.20, U2.5
+5V: C7.2, D2.2, P2.4, U2.1, U2.3
+12V: C5.2, IC1.5, P3.1
GND: C1.2, C2.2, C3.2, C7.1, C12.2, C13.2, DI1.24, DI1.25, DI1.26, DI1.30, P1.2, P2.3, P4.2, R13.2, SW3.2, SW3.4, U1.8, U1.11, U1.12, U1.13, U1.19, U2.2
GNDA: C5.1, C6.1, D1.2, IC1.2, P3.2, R9.1, R11.2, R12.2, R13.1
unnamed: C2.1, U1.6
unnamed: C4.1, D2.1, IC1.1
unnamed: C4.2, D1.1, IC1.6, L1.1
unnamed: C6.2, DI1.1, L1.2
unnamed: C8.1, C9.1, DI1.18
unnamed: C8.2, C9.2, DI1.21
unnamed: C10.1, C11.1, DI1.19
unnamed: C10.2, C11.2, DI1.20
unnamed: C13.1, DI1.17
unnamed: DI1.2, DI1.14
unnamed: DI1.3, DI1.15
unnamed: DI1.16, IC1.3, R11.1, R12.1
unnamed: DI1.27, U1.10
unnamed: DI1.28, U1.9
unnamed: DI1.29, U1.5
unnamed: DI1.31, U1.3
unnamed: DI1.32, U1.2
unnamed: IC1.4, R9.2, U1.23
unnamed: P1.1, R10.1, U1.1
unnamed: P1.3, U1.28
unnamed: P1.4, U1.27
unnamed: P2.1, U1.16
unnamed: P2.2, U1.15
unnamed: P4.1, R1.1
unnamed: P4.3, R4.1, SW3.5, U1.4
unnamed: R1.2, U1.24
unnamed: R2.2, SW3.1, U1.25
unnamed: R3.2, SW3.3, U1.26

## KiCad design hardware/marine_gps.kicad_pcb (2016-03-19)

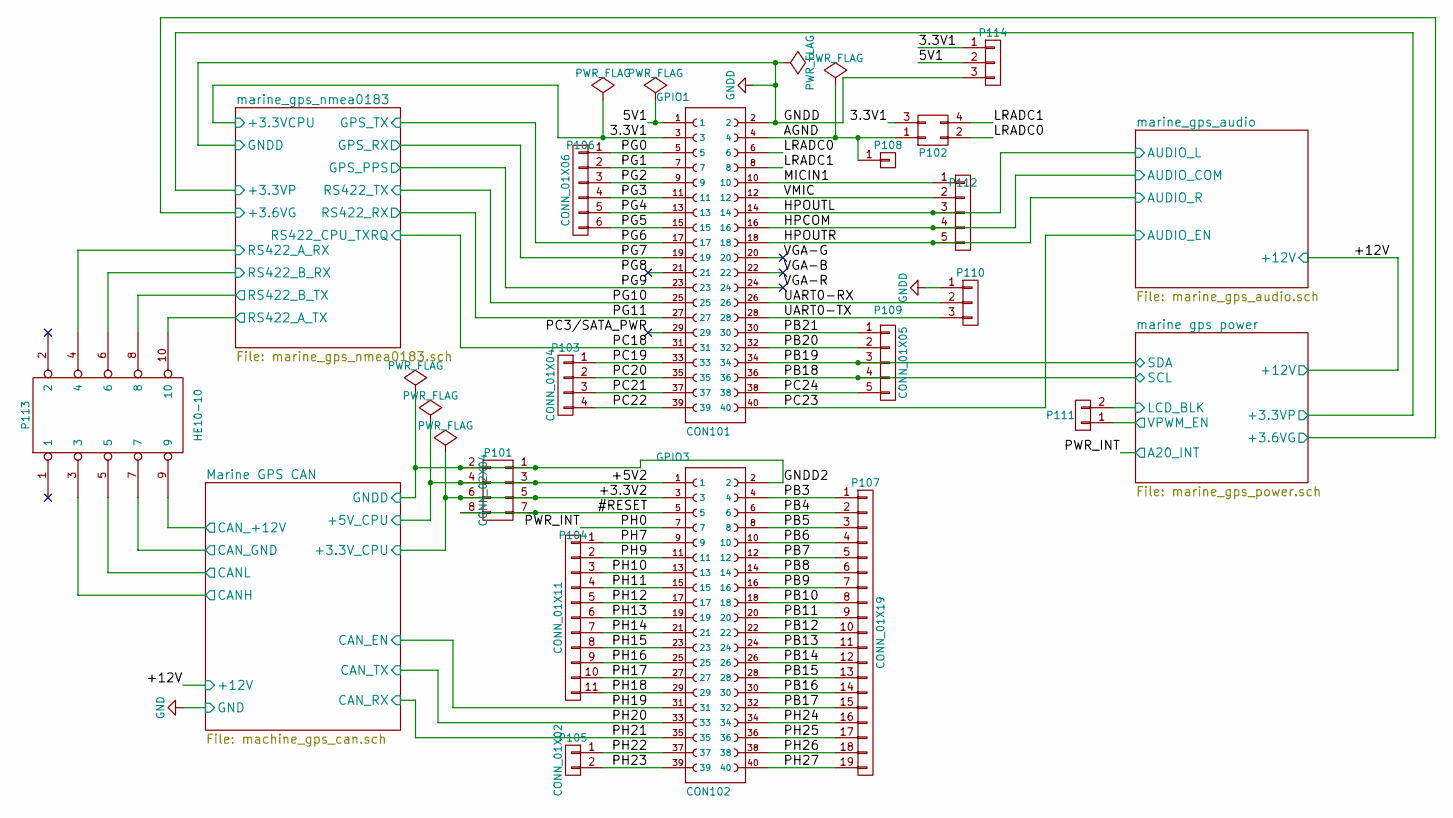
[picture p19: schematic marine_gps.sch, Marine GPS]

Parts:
CON101: GPIO1; A10_OLIMEXINO_LIME_SHIELD_1-YA-V36P-2X20-LF
CON102: GPIO3; A10_OLIMEXINO_LIME_SHIELD_1-YA-V36P-2X20-LF
P101: CONN_02X04; Pin_Header_Angled_2x04
P102: CONN_02X02; Pin_Header_Angled_2x02
P103: CONN_01X04; Pin_Header_Straight_1x04
P104: CONN_01X11; Pin_Header_Straight_1x11
P105, P111: CONN_01X02; Pin_Header_Straight_1x02
P106: CONN_01X06; Pin_Header_Straight_1x06
P107: CONN_01X19; Pin_Header_Straight_1x19
P108: CONN_01X01; Pin_Header_Straight_1x01
P109, P112: CONN_01X05; Pin_Header_Straight_1x05
P110: CONN_01X03; Pin_Header_Straight_1x03
P113: HE10-10; HE10-10C
P114: CONN_01X03; Pin_Header_Angled_1x03

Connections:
/5V1: CON101.1, P114.2
/#RESET: CON102.5, P101.7, P101.8
/AGND: CON101.4, P102.1, P108.1
/LRADC0: CON101.6, P102.2
/LRADC1: CON101.8, P102.4
/MICIN1: CON101.10, P112.1
/Marine GPS CAN/+3.3V_CPU: CON102.3, P101.5, P101.6; also elsewhere on the board
/Marine GPS CAN/+5V_CPU: CON102.1, P101.3, P101.4; also elsewhere on the board
/Marine GPS CAN/CANH: P113.3; also elsewhere on the board
/Marine GPS CAN/CANL: P113.5; also elsewhere on the board
/Marine GPS CAN/CAN_+12V: P113.9; also elsewhere on the board
/Marine GPS CAN/CAN_EN: CON102.31; also elsewhere on the board
/Marine GPS CAN/CAN_RX: CON102.35; also elsewhere on the board
/Marine GPS CAN/CAN_TX: CON102.33; also elsewhere on the board
/Marine GPS CAN/GNDD: CON102.2, P101.1, P101.2; also elsewhere on the board
/PB3: CON102.4, P107.1
/PB4: CON102.6, P107.2
/PB5: CON102.8, P107.3
/PB6: CON102.10, P107.4
/PB7: CON102.12, P107.5
/PB8: CON102.14, P107.6
/PB9: CON102.16, P107.7
/PB10: CON102.18, P107.8
/PB11: CON102.20, P107.9
/PB12: CON102.22, P107.10
/PB13: CON102.24, P107.11
/PB14: CON102.26, P107.12
/PB15: CON102.28, P107.13
/PB16: CON102.30, P107.14
/PB17: CON102.32, P107.15
/PB20: CON101.32, P109.2
/PB21: CON101.30, P109.1
/PC3/SATA_PWR: CON101.29
/PC19: CON101.33, P103.1
/PC20: CON101.35, P103.2
/PC21: CON101.37, P103.3
/PC22: CON101.39, P103.4
/PC24: CON101.38, P109.5
/PG0: CON101.5, P106.1
/PG1: CON101.7, P106.2
/PG2: CON101.9, P106.3
/PG3: CON101.11, P106.4
/PG4: CON101.13, P106.5
/PG5: CON101.15, P106.6
/PG8: CON101.21
/PH7: CON102.9, P104.1
/PH9: CON102.11, P104.2
/PH10: CON102.13, P104.3
/PH11: CON102.15, P104.4
/PH12: CON102.17, P104.5
/PH13: CON102.19, P104.6
/PH14: CON102.21, P104.7
/PH15: CON102.23, P104.8
/PH16: CON102.25, P104.9
/PH17: CON102.27, P104.10
/PH18: CON102.29, P104.11
/PH22: CON102.37, P105.1
/PH23: CON102.39, P105.2
/PH24: CON102.34, P107.16
/PH25: CON102.36, P107.17
/PH26: CON102.38, P107.18
/PH27: CON102.40, P107.19
/UART0-RX: CON101.26, P110.2
/UART0-TX: CON101.28, P110.3
/VGA-B: CON101.22
/VGA-G: CON101.20
/VGA-R: CON101.24
/VMIC: CON101.12, P112.2
/marine gps power/A20_INT: CON102.7; also elsewhere on the board
/marine gps power/LCD_BLK: P111.2; also elsewhere on the board
/marine gps power/SCL: CON101.36, P109.4; also elsewhere on the board
/marine gps power/SDA: CON101.34, P109.3; also elsewhere on the board
/marine gps power/VPWM_EN: P111.1; also elsewhere on the board
/marine_gps_audio/AUDIO_COM: CON101.16, P112.4; also elsewhere on the board
/marine_gps_audio/AUDIO_EN: CON101.40; also elsewhere on the board
/marine_gps_audio/AUDIO_L: CON101.14, P112.3; also elsewhere on the board
/marine_gps_audio/AUDIO_R: CON101.18, P112.5; also elsewhere on the board
/marine_gps_nmea0183/GPS_PPS: CON101.23; also elsewhere on the board
/marine_gps_nmea0183/GPS_RX: CON101.19; also elsewhere on the board
/marine_gps_nmea0183/GPS_TX: CON101.17; also elsewhere on the board
/marine_gps_nmea0183/RS422_A_RX: P113.4; also elsewhere on the board
/marine_gps_nmea0183/RS422_A_TX: P113.10; also elsewhere on the board
/marine_gps_nmea0183/RS422_B_RX: P113.6; also elsewhere on the board
/marine_gps_nmea0183/RS422_B_TX: P113.8; also elsewhere on the board
/marine_gps_nmea0183/RS422_CPU_TXRQ: CON101.31; also elsewhere on the board
/marine_gps_nmea0183/RS422_RX: CON101.27; also elsewhere on the board
/marine_gps_nmea0183/RS422_TX: CON101.25; also elsewhere on the board
GND: P113.7; also elsewhere on the board
GND2: CON101.2, P110.1, P114.3; also elsewhere on the board
VCC2: CON101.3, P102.3, P114.1; also elsewhere on the board

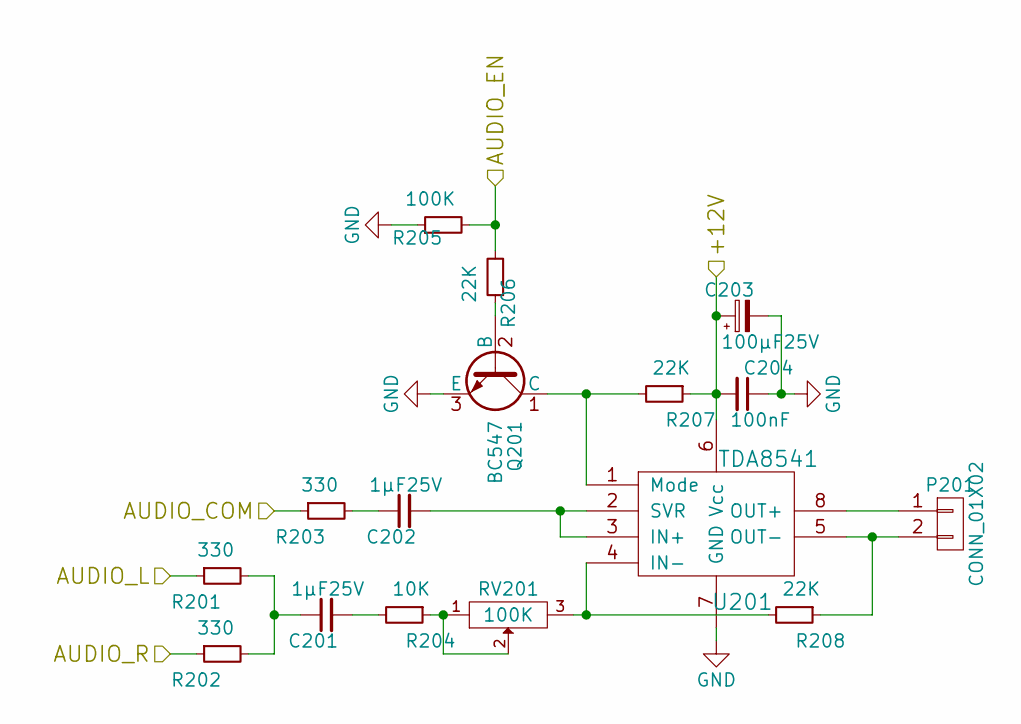
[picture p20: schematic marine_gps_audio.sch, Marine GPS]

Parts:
C201, C202: 1µF25V; C_0805
C203: 100µF25V; C_Radial_D6.3_L11.2_P2.5
C204: 100nF; C_0805
P201: CONN_01X02; Pin_Header_Straight_1x02
Q201: BC547; TO-92_Molded_Narrow
R201, R202, R203: 330; Resistor_Horizontal_RM15mm
R204: 10K; Resistor_Horizontal_RM15mm
R205: 100K; Resistor_Horizontal_RM10mm
R206: 22K; Resistor_Horizontal_RM10mm
R207, R208: 22K; Resistor_Horizontal_RM15mm
RV201: 100K; CB10LV
U201: TDA8541; SOIC-8-N

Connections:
+12V: C203.1, C204.2, R207.1, U201.6 (Vcc); also elsewhere on the board
/marine_gps_audio/AUDIO_COM: R203.1; also elsewhere on the board
/marine_gps_audio/AUDIO_EN: R205.2, R206.2; also elsewhere on the board
/marine_gps_audio/AUDIO_L: R201.1; also elsewhere on the board
/marine_gps_audio/AUDIO_R: R202.1; also elsewhere on the board
GND: C203.2, C204.1, Q201.3 (E), R205.1, U201.7 (GND); also elsewhere on the board
unnamed: C201.1, R201.2, R202.2
unnamed: C201.2, R204.2
unnamed: C202.1, R203.2
unnamed: C202.2, U201.2 (SVR), U201.3 (IN+)
unnamed: P201.1, U201.8 (OUT+)
unnamed: P201.2, R208.1, U201.5 (OUT-)
unnamed: Q201.1 (C), R207.2, U201.1 (Mode)
unnamed: Q201.2 (B), R206.1
unnamed: R204.1, RV201.1, RV201.2
unnamed: R208.2, RV201.3, U201.4 (IN-)

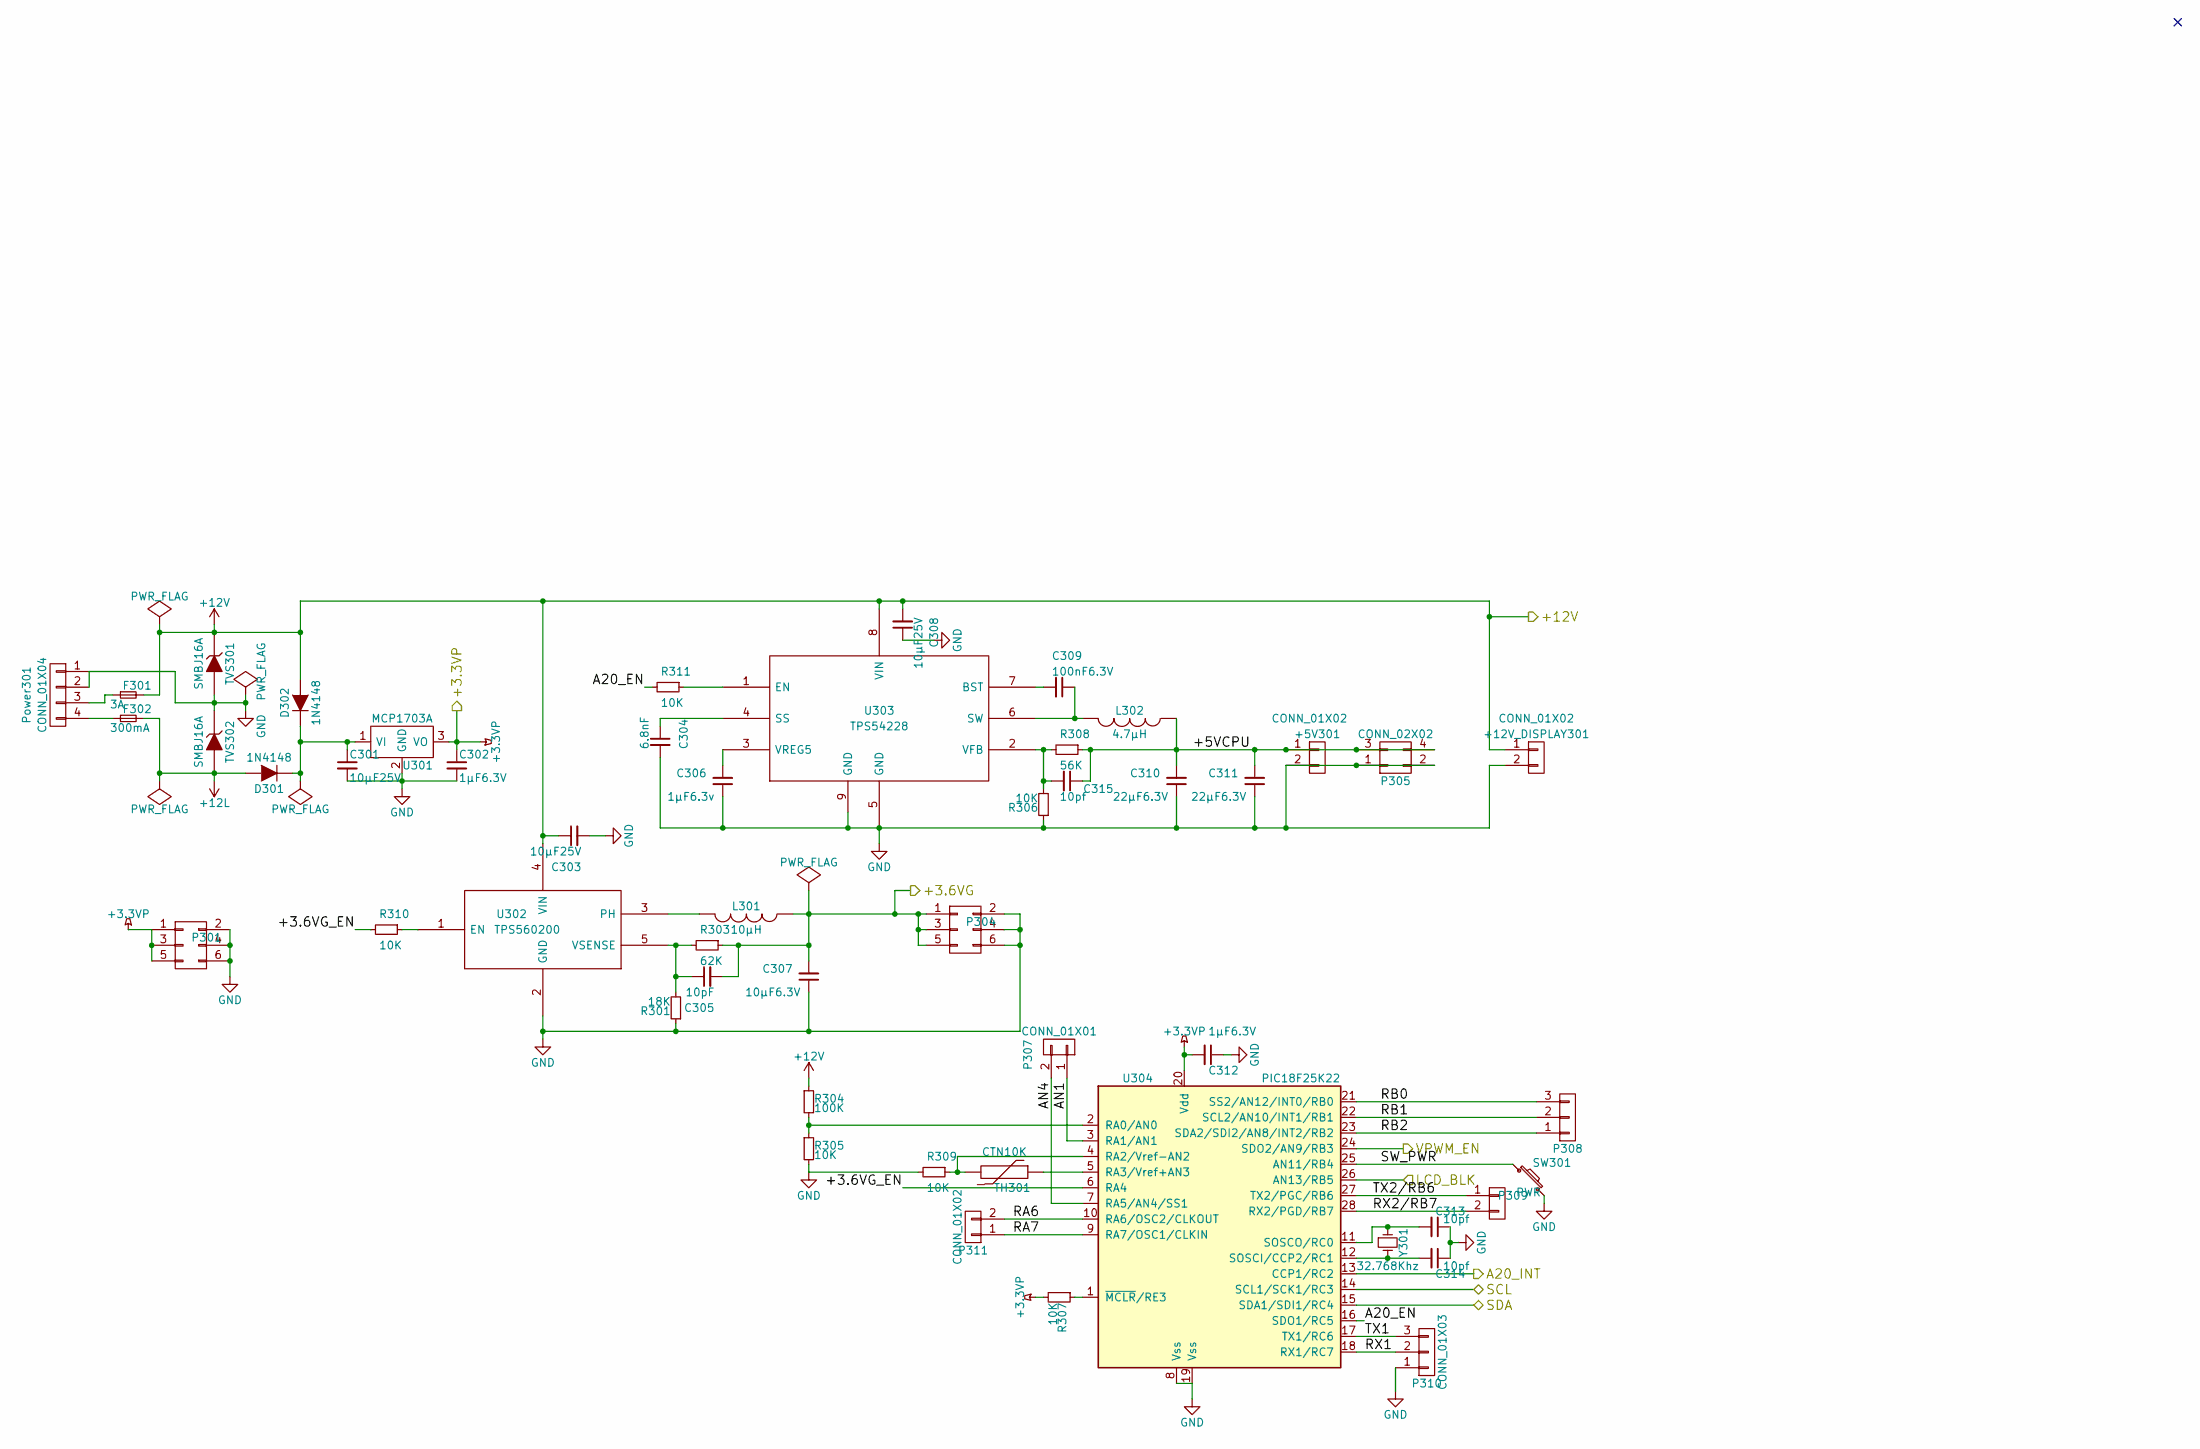
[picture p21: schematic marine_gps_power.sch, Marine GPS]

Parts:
+5V301, +12V_DISPLAY301: CONN_01X02; Pin_Header_Straight_1x02
C301, C303, C308: 10µF25V; C_1210
C302, C312: 1µF6.3V; C_0805
C304: 6.8nF; C_0603_HandSoldering
C305: 10pF; C_0603_HandSoldering
C306: 1µF6.3v; C_0805
C307: 10µF6.3V; C_1210
C309: 100nF6.3V; C_0805
C310, C311: 22µF6.3V; C_1210
C313, C314, C315: 10pf; C_0603_HandSoldering
D301, D302: 1N4148; Diode_DO-35_SOD27_Horizontal_RM10
F301: 3A; Fuseholder5x20_horiz_SemiClosed_Casing10x22.5mm
F302: 300mA; Fuseholder5x20_horiz_SemiClosed_Casing10x22.5mm
L301: 10µH; Choke_SMD_7.3x7.3_H4.5
L302: 4.7µH; Choke_SMD_10.4x10.4_H4.8
P301, P304: CONN_02X03; Pin_Header_Angled_2x03
P305: CONN_02X02; Pin_Header_Angled_2x02
P307: CONN_01X01; Pin_Header_Straight_1x02
P308, P310: CONN_01X03; Pin_Header_Angled_1x03
P309, P311: CONN_01X02; Pin_Header_Straight_1x02
Power301: CONN_01X04; minifit-4
R301: 18K; Resistor_Horizontal_RM15mm
R303: 62K; Resistor_Horizontal_RM15mm
R304: 100K; Resistor_Horizontal_RM10mm
R305, R310, R311: 10K; Resistor_Horizontal_RM10mm
R306, R307: 10K; R_1210_HandSoldering
R308: 56K; R_1210_HandSoldering
R309: 10K; Resistor_Horizontal_RM15mm
SW301: PWR; Pin_Header_Angled_1x02
TH301: CTN10K; Pin_Header_Straight_1x02
TVS301, TVS302: SMBJ16A; DO-214AB
U301: MCP1703A; SOT-223-Tto2
U302: TPS560200; SOT-23-5
U303: TPS54228; SOIC-8-1EP_3.9x4.9mm_Pitch1.27mm
U304: PIC18F25K22; DIP-28_W7.62mm_LongPads
Y301: 32.768Khz; CMR200T

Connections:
+3.3VP: C302.1, C312.2, P301.1, P301.3, P301.5, R307.2, U301.3 (VO), U304.20 (Vdd); also elsewhere on the board
+12L: D301.2 (A), F302.2, TVS302.2 (A)
+12V: +12V_DISPLAY301.1, C303.1, C308.2, D302.2 (A), F301.2, R304.1, TVS301.1 (K), U302.4 (VIN), U303.8 (VIN); also elsewhere on the board
/marine gps power/+3.6VG_EN: R310.2, U304.6 (RA4)
/marine gps power/+5VCPU: +5V301.1, C310.2, C311.2, C315.1, L302.1, P305.3, P305.4, R308.1
/marine gps power/A20_EN: R311.2, U304.16 (SDO1/RC5)
/marine gps power/A20_INT: U304.13 (CCP1/RC2); also elsewhere on the board
/marine gps power/AN1: P307.1, U304.3 (RA1/AN1)
/marine gps power/AN4: P307.2, U304.7 (RA5/AN4/SS1)
/marine gps power/LCD_BLK: U304.26 (AN13/RB5); also elsewhere on the board
/marine gps power/RA6: P311.2, U304.10 (RA6/OSC2/CLKOUT)
/marine gps power/RA7: P311.1, U304.9 (RA7/OSC1/CLKIN)
/marine gps power/RB0: P308.3, U304.21 (SS2/AN12/INT0/RB0)
/marine gps power/RB1: P308.2, U304.22 (SCL2/AN10/INT1/RB1)
/marine gps power/RB2: P308.1, U304.23 (SDA2/SDI2/AN8/INT2/RB2)
/marine gps power/RX1: P310.2, U304.18 (RX1/RC7)
/marine gps power/RX2/RB7: P309.2, U304.28 (RX2/PGD/RB7)
/marine gps power/SCL: U304.14 (SCL1/SCK1/RC3); also elsewhere on the board
/marine gps power/SDA: U304.15 (SDA1/SDI1/RC4); also elsewhere on the board
/marine gps power/SW_PWR: SW301.1, U304.25 (AN11/RB4)
/marine gps power/TX1: P310.3, U304.17 (TX1/RC6)
/marine gps power/TX2/RB6: P309.1, U304.27 (TX2/PGC/RB6)
/marine gps power/VPWM_EN: U304.24 (SDO2/AN9/RB3); also elsewhere on the board
GND: +5V301.2, +12V_DISPLAY301.2, C301.2, C302.2, C303.2, C304.2, C306.1, C307.1, C308.1, C310.1, C311.1, C312.1, C313.1, C314.1, P301.2, P301.4, P301.6, P304.2, P304.4, P304.6, P305.1, P305.2, P310.1, Power301.1, Power301.2, R301.1, R305.2, R306.1, R309.2, SW301.2, TVS301.2 (A), TVS302.1 (K), U301.2 (GND), U302.2 (GND), U303.5 (GND), U303.9 (GND), U304.8 (Vss), U304.19 (Vss); also elsewhere on the board
unnamed: C301.1, D301.1 (K), D302.1 (K), U301.1 (VI)
unnamed: C304.1, U303.4 (SS)
unnamed: C305.1, R301.2, R303.2, U302.5 (VSENSE)
unnamed: C306.2, U303.3 (VREG5)
unnamed: C309.1, L302.2, U303.6 (SW)
unnamed: C309.2, U303.7 (BST)
unnamed: C313.2, U304.11 (SOSCO/RC0), Y301.1
unnamed: C314.2, U304.12 (SOSCI/CCP2/RC1), Y301.2
unnamed: C315.2, R306.2, R308.2, U303.2 (VFB)
unnamed: F301.1, Power301.3
unnamed: F302.1, Power301.4
unnamed: L301.2, U302.3 (PH)
unnamed: R304.2, R305.1, U304.2 (RA0/AN0)
unnamed: R307.1, U304.1 (~MCLR~/RE3)
unnamed: R309.1, TH301.2, U304.4 (RA2/Vref-AN2)
unnamed: R310.1, U302.1 (EN)
unnamed: R311.1, U303.1 (EN)
unnamed: TH301.1, U304.5 (RA3/Vref+AN3)
VCC: C305.2, C307.2, L301.1, P304.1, P304.3, P304.5, R303.1; also elsewhere on the board

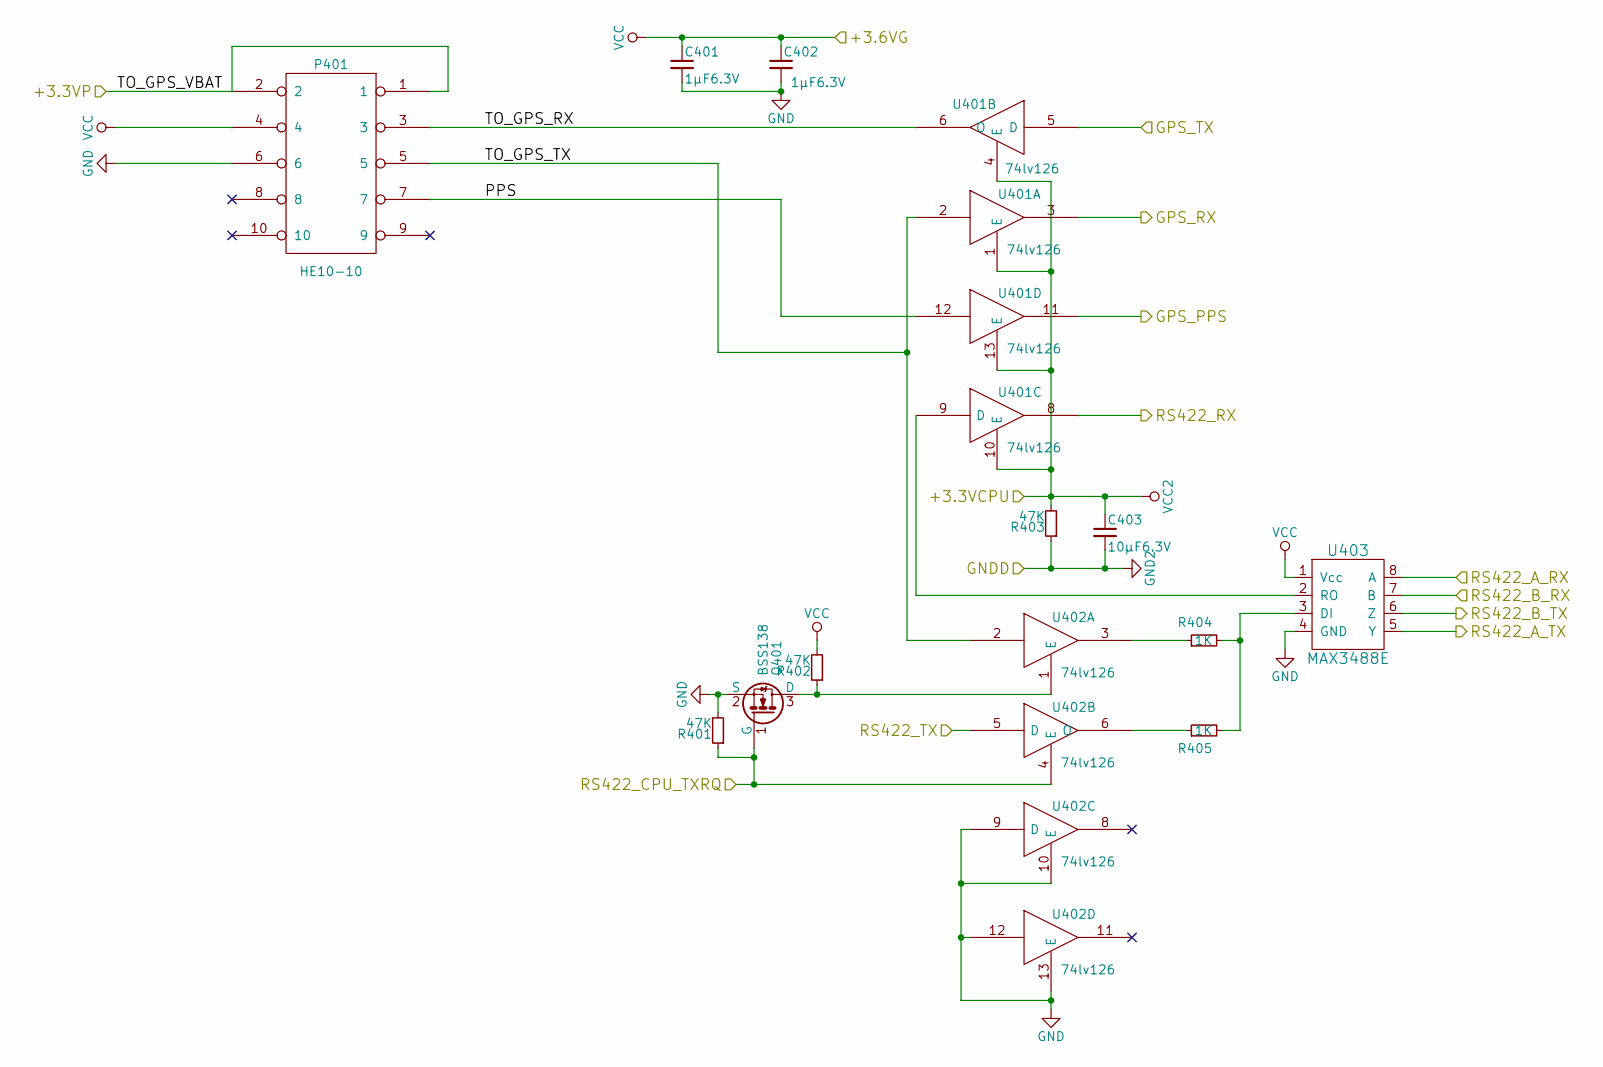
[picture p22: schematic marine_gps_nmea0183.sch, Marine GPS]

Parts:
C401, C402: 1µF6.3V; C_1210
C403: 10µF6.3V; C_1210
P401: HE10-10; HE10-10C
Q401: BSS138; SOT-23
R401, R402, R403: 47K; Resistor_Horizontal_RM15mm
R404, R405: 1K; Resistor_Horizontal_RM15mm
U401, U402: 74lv126; SOIC-14_3.9x8.7mm_Pitch1.27mm
U403: MAX3488E; SOIC-8_3.9x4.9mm_Pitch1.27mm

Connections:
+3.3VP: P401.1, P401.2; also elsewhere on the board
/marine_gps_nmea0183/GPS_PPS: U401.11; also elsewhere on the board
/marine_gps_nmea0183/GPS_RX: U401.3; also elsewhere on the board
/marine_gps_nmea0183/GPS_TX: U401.5 (D); also elsewhere on the board
/marine_gps_nmea0183/PPS: P401.7, U401.12
/marine_gps_nmea0183/RS422_A_RX: U403.8 (A); also elsewhere on the board
/marine_gps_nmea0183/RS422_A_TX: U403.5 (Y); also elsewhere on the board
/marine_gps_nmea0183/RS422_B_RX: U403.7 (B); also elsewhere on the board
/marine_gps_nmea0183/RS422_B_TX: U403.6 (Z); also elsewhere on the board
/marine_gps_nmea0183/RS422_CPU_TXRQ: Q401.1 (G), R401.1, U402.4 (E); also elsewhere on the board
/marine_gps_nmea0183/RS422_RX: U401.8; also elsewhere on the board
/marine_gps_nmea0183/RS422_TX: U402.5 (D); also elsewhere on the board
/marine_gps_nmea0183/TO_GPS_RX: P401.3, U401.6 (O)
/marine_gps_nmea0183/TO_GPS_TX: P401.5, U401.2, U402.2
GND: C401.2, C402.2, P401.6, Q401.2 (S), R401.2, U402.7 (GND), U402.9 (D), U402.10 (E), U402.12, U402.13 (E), U403.4 (GND); also elsewhere on the board
GND2: C403.2, R403.1, U401.7 (GND2); also elsewhere on the board
unnamed: Q401.3 (D), R402.1, U402.1 (E)
unnamed: R404.1, U402.3
unnamed: R404.2, R405.2, U403.3 (DI)
unnamed: R405.1, U402.6 (O)
unnamed: U401.9 (D), U403.2 (RO)
VCC: C401.1, C402.1, P401.4, R402.2, U402.14 (VCC), U403.1 (Vcc); also elsewhere on the board
VCC2: C403.1, R403.2, U401.1 (E), U401.4 (E), U401.10 (E), U401.13 (E), U401.14 (VCC2); also elsewhere on the board

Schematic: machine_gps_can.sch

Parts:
C501, C502: 1µF6.3V; C_0805
P501: CONN_01X02; Pin_Header_Straight_1x02
Q501, Q502: BSS138; SOT-23
Q503: DMG2307L; SOT-23
R501: 47K; Resistor_Horizontal_RM15mm
R502: 47K; Resistor_Horizontal_RM10mm
U501: MCP2562; DIP-8_W7.62mm

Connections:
+12V: Q503.2, R502.1; also elsewhere on the board
/Marine GPS CAN/+3.3V_CPU: C502.2, U501.5 (VIO); also elsewhere on the board
/Marine GPS CAN/+5V_CPU: C501.1, U501.3 (VDD); also elsewhere on the board
/Marine GPS CAN/CANH: U501.7 (CANH); also elsewhere on the board
/Marine GPS CAN/CANL: U501.6 (CANL); also elsewhere on the board
/Marine GPS CAN/CAN_+12V: P501.2; also elsewhere on the board
/Marine GPS CAN/CAN_EN: Q501.1 (G), Q502.1 (G), R501.2; also elsewhere on the board
/Marine GPS CAN/CAN_RX: U501.4 (RXD); also elsewhere on the board
/Marine GPS CAN/CAN_TX: U501.1 (TXD); also elsewhere on the board
/Marine GPS CAN/GNDD: C501.2, C502.1, Q501.2 (S), Q502.2 (S), R501.1, U501.2 (VSS); also elsewhere on the board
unnamed: P501.1, Q503.3
unnamed: Q501.3 (D), U501.8 (STB)
unnamed: Q502.3 (D), Q503.1, R502.2

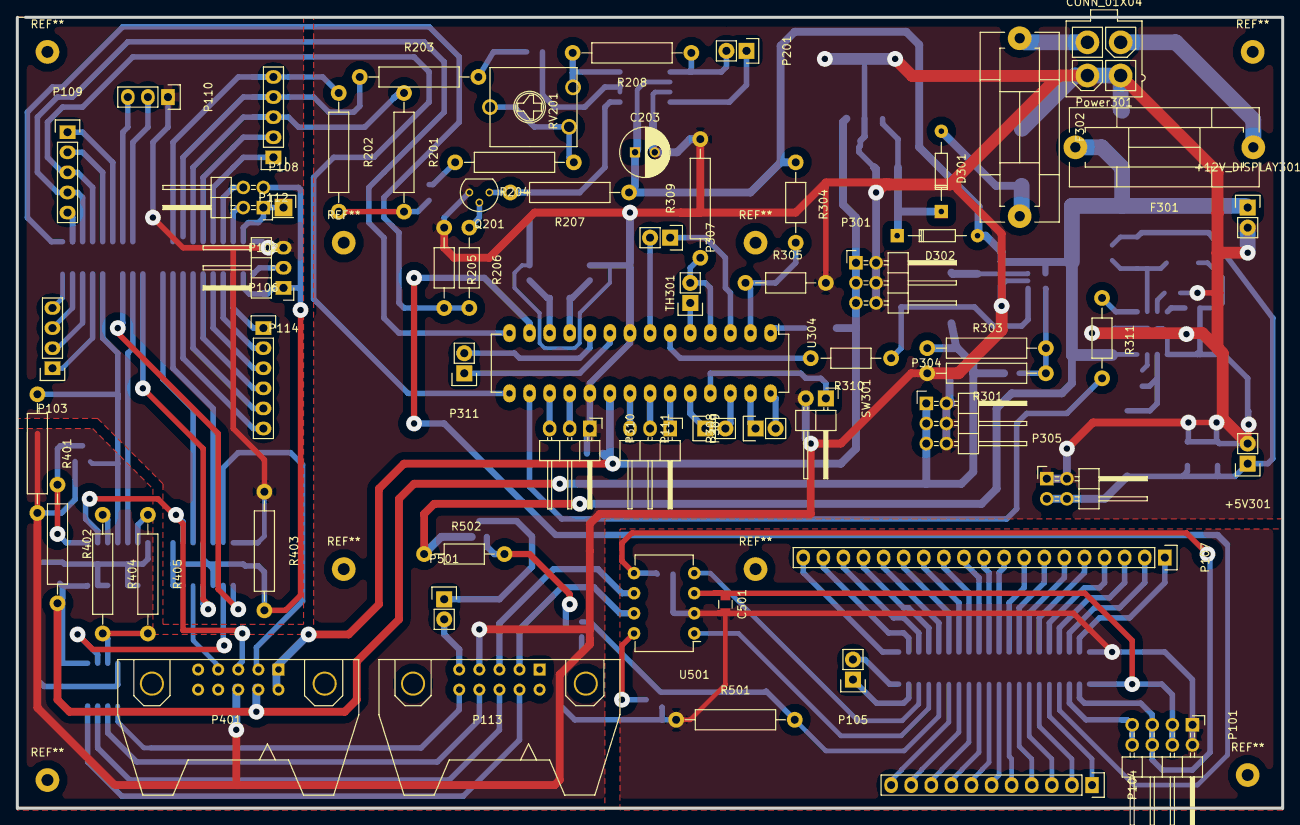
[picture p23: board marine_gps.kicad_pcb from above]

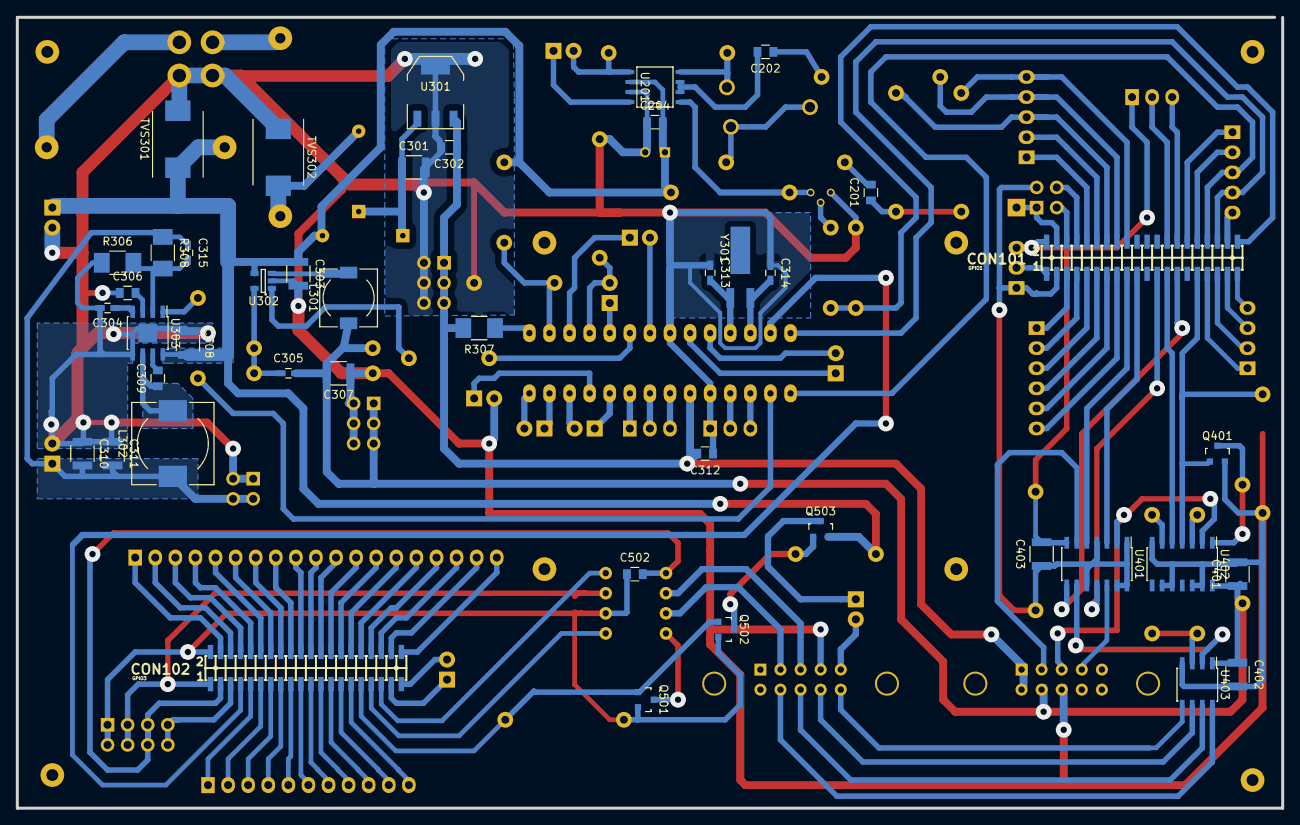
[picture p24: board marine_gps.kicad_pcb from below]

Board: 2 copper layers, 160.0 x 100.0 mm, 107 parts (43 on the bottom side), 143 nets.

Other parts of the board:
EU160: EuroBoard160mmX100mm
LIME2: LIME2; A20_OLIMEXINO_LIME_SHIELD

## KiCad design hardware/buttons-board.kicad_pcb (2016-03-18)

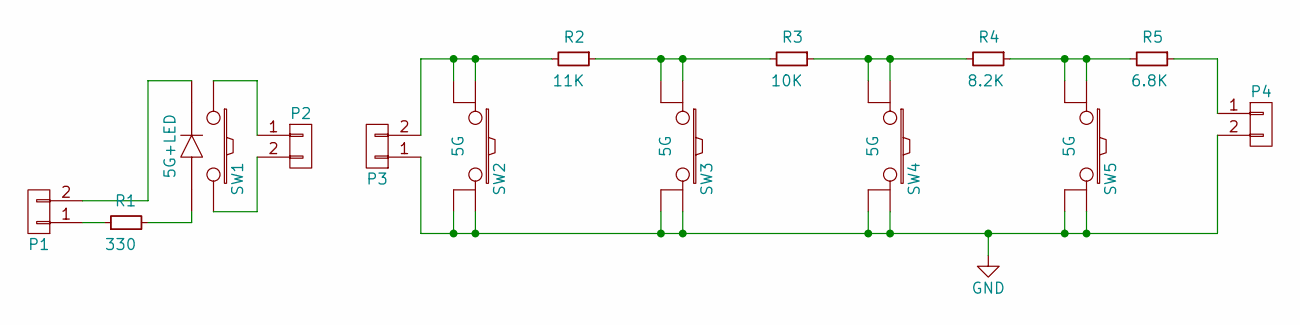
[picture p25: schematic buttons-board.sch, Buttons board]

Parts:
P1, P2, P3, P4: CONN_01X02; solder_2x5mm
R1: 330; Resistor_Horizontal_RM10mm
R2: 11K; Resistor_Horizontal_RM10mm
R3: 10K; Resistor_Horizontal_RM10mm
R4: 8.2K; Resistor_Horizontal_RM10mm
R5: 6.8K; Resistor_Horizontal_RM10mm
SW1: 5G+LED; 5G-1US
SW2, SW3, SW4, SW5: 5G; 5G-1US

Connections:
GND: P3.1, P4.2, SW2.3, SW2.4, SW3.3, SW3.4, SW4.3, SW4.4, SW5.3, SW5.4
unnamed: P1.1, R1.1
unnamed: P1.2, SW1.2 (-)
unnamed: P2.1, SW1.1
unnamed: P2.2, SW1.4
unnamed: P3.2, R2.2, SW2.1, SW2.2
unnamed: P4.1, R5.1
unnamed: R1.2, SW1.3 (+)
unnamed: R2.1, R3.2, SW3.1, SW3.2
unnamed: R3.1, R4.2, SW4.1, SW4.2
unnamed: R4.1, R5.2, SW5.1, SW5.2

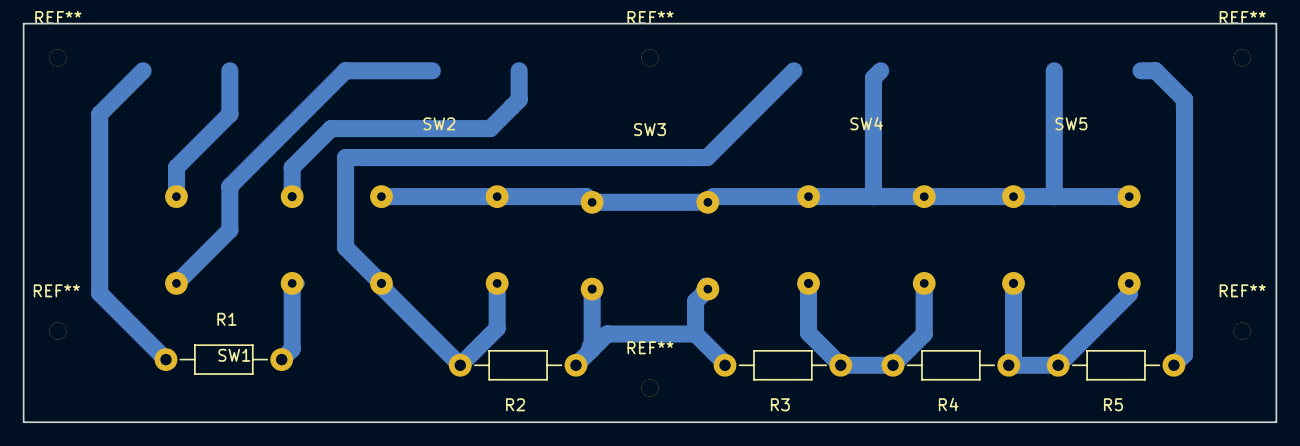
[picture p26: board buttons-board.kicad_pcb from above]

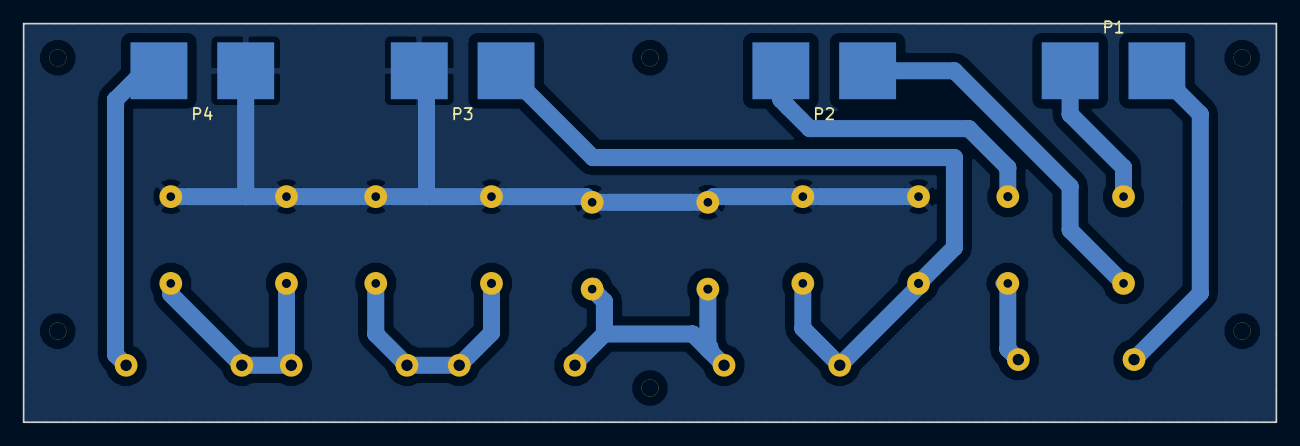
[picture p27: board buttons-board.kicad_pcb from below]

Board: 2 copper layers, 110.0 x 35.0 mm, 14 parts (4 on the bottom side), 11 nets.

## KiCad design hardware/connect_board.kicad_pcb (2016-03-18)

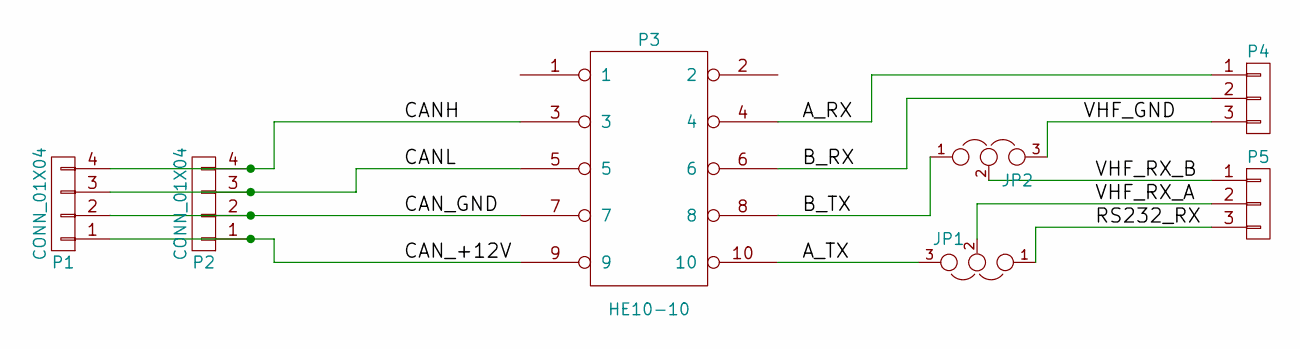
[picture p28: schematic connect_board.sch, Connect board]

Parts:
JP1, JP2: JUMPER3; Pin_Header_Straight_1x03
P1, P2: CONN_01X04; phoenix_1770979
P3: HE10-10; he10s-10d
P4, P5: CONN_01X03; TerminalBlock_Pheonix_MPT-2.54mm_3pol

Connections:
/A_RX: P3.4, P4.1
/A_TX: JP1.3, P3.10
/B_RX: P3.6, P4.2
/B_TX: JP2.1, P3.8
/CANH: P1.4, P2.4, P3.3
/CANL: P1.3, P2.3, P3.5
/CAN_+12V: P1.1, P2.1, P3.9
/CAN_GND: P1.2, P2.2, P3.7
/RS232_RX: JP1.1, P5.3
/VHF_GND: JP2.3, P4.3
/VHF_RX_A: JP1.2, P5.2
/VHF_RX_B: JP2.2, P5.1


Board: 2 copper layers, 61.0 x 34.3 mm, 7 parts (0 on the bottom side), 12 nets.

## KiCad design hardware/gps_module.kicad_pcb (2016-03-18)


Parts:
C101, C102: 1µF; C_0805_HandSoldering
P101: HE10-10; he10s-10d
P102: CONN_01X01; Pin_Header_Straight_1x01
U101: microstack_GPS; microstack
U102: MCP1703A; SOT-223-Tto2

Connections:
/GND: C101.2, C102.2, P101.6, U101.6 (GND), U102.2 (GND)
/GPS_RX: P101.3, U101.8 (RX)
/GPS_TX: P101.5, U101.7 (TX)
/PPS: P101.7, U101.9 (PPS)
/VBATT: P101.1, P102.1
/VCC: C101.1, P101.4, U102.1 (VI)
unnamed: C102.1, U101.2 (+3.3V), U102.3 (VO)
unnamed: P101.9, U101.10 (WAKE)



Board: 2 copper layers, 58.4 x 21.6 mm, 6 parts (3 on the bottom side), 8 nets.

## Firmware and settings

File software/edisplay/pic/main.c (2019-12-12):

/*
 *  Copyright (c) 2019 Manuel Bouyer.
 *
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
 *  THIS SOFTWARE IS PROVIDED BY THE AUTHOR ``AS IS'' AND ANY EXPRESS OR
 *  IMPLIED WARRANTIES, INCLUDING, BUT NOT LIMITED TO, THE IMPLIED WARRANTIES
 *  OF MERCHANTABILITY AND FITNESS FOR A PARTICULAR PURPOSE ARE DISCLAIMED.
 *  IN NO EVENT SHALL THE AUTHOR BE LIABLE FOR ANY DIRECT, INDIRECT,
 *  INCIDENTAL, SPECIAL, EXEMPLARY, OR CONSEQUENTIAL DAMAGES (INCLUDING, BUT
 *  NOT LIMITED TO, PROCUREMENT OF SUBSTITUTE GOODS OR SERVICES; LOSS OF USE,
 *  DATA, OR PROFITS; OR BUSINESS INTERRUPTION) HOWEVER CAUSED AND ON ANY
 *  THEORY OF LIABILITY, WHETHER IN CONTRACT, STRICT LIABILITY, OR TORT
 *  (INCLUDING NEGLIGENCE OR OTHERWISE) ARISING IN ANY WAY OUT OF THE USE OF
 *  THIS SOFTWARE, EVEN IF ADVISED OF THE POSSIBILITY OF SUCH DAMAGE.
 */

#include <pic18fregs.h>
#include <stdio.h>
#include "comms.h"
#include "usb.h"
#include "lcd.h"
#include "spi.h"


unsigned char sending;

extern char stack;
extern char stack_end;
byte i,rr;
short rb;
#pragma stack 0x100 256

static char counter_1hz;
static volatile short counter_10hz;
#define TIMER2_10HZ 100
static volatile unsigned char softintrs;
#define INT_10HZ        (unsigned char)0x01
#define INT_ADDONE      (unsigned char)0x02
#define INT_ST_CH       (unsigned char)0x04

#define TIMER0_5MS 192 /* 48 without PLL */

union rot_status {
	struct {
		unsigned rotary_a       : 1;
		unsigned rotary_b       : 1;
		unsigned pending_a      : 1;
		unsigned pending_b      : 1;
	} s;
	unsigned char v;
};

static union rot_status rot_status;
static volatile char rotary_pos;
static unsigned char rotary_a;
static unsigned char rotary_b;

union buttons_status {
	struct {
		unsigned b1       : 1;
		unsigned b2       : 1;
		unsigned b3       : 1;
		unsigned b4       : 1;
		unsigned br       : 1;
	} s;
	unsigned char v;
};

static volatile union buttons_status buttons_status;
static unsigned char button1;
static unsigned char button2;
static unsigned char button3;
static unsigned char button4;
static unsigned char buttonr;


void _reset (void) __naked __interrupt 0;
void _startup (void) __naked;
static void usart_putchar(unsigned char arg) __wparam;
static void InitializeSystem(void);
void USBTasks(void);
char *txbuf_prod; /* producer index in txbuf */
char *txbuf_cons; /* consumer index in txbuf */

#define UART_BUFSIZE 256
#define UART_BUFSIZE_MASK 0xff


unsigned char ad_result;

#define ROTARY_A PORTBbits.RB4        /* Encoder A Pin */
#define ROTARY_B PORTBbits.RB5        /* Encoder B Pin */

#define LED_OUT LATBbits.LATB3
#define LED_PWM CCPR2L
#define BACKLIGHT_OUT LATBbits.LATB2
#define BACKLIGHT_PWM CCPR1L

static struct comm_status comm_status;
static char rxBuffer[VENDOR_OUTPUT_INTR_BYTES];

#define RCMD ((struct comm_command *)rxBuffer)

char uart_txbuf[UART_BUFSIZE];
unsigned char uart_txbuf_prod, uart_txbuf_cons;

void
__stream_usart_putchar(unsigned char c) __wparam __naked
{
	c;
	__asm
	call _usart_putchar;
	return;
	__endasm;
}

static void
usart_putchar(unsigned char c) __wparam
{
	unsigned char new_uart_txbuf_prod;

again:
	new_uart_txbuf_prod = (uart_txbuf_prod + 1) & UART_BUFSIZE_MASK;
	while (new_uart_txbuf_prod == uart_txbuf_cons) {
		PIE3bits.TX2IE = 1; /* ensure we'll make progress */
	}
	uart_txbuf[uart_txbuf_prod] = c;
	uart_txbuf_prod = new_uart_txbuf_prod;
 	PIE3bits.TX2IE = 1; /* start transmit  */

	if (c == '\n') {
		c = '\r';
		goto again;
	}
}

PUTCHAR(c) /* Macro */
{
	usart_putchar(c);
}

char
getchar(void)
{
	char c;
	while (!PIR3bits.RC2IF); /* wait for a char */
	c = RCREG2;
	if (RCSTA2bits.OERR) {
		RCSTA2bits.CREN = 0;
		RCSTA2bits.CREN = 1;
	}
	return c;
}

void
flushtx(void)
{
	while (PIE3bits.TX2IE)
		;
}


static void
process_char(char c) __wparam
{
	if (c == 'r') {
		printf("reset\r\n"); flushtx();
		__asm__("reset");
	}
}

static inline void
checkrx(void)
{
	CS0 = 1;
	if ((rb = VENDORRxBulk()) != 0) {
		CS0 = 0;
		CD=DATA;
		DMACON1 = 0x24; /* auto-inc, half duplex TX */
		DMACON2 = 0x00; /* 1 Tcy inter-byte delay */
		DMABCH = 0;
		DMABCL = ((rb & 0xff) - 1);
		if ((rb & 0x100) == 0) {
			TXADDRH = ((int)VENDORRxBufferB0 >> 8);
			TXADDRL = ((int)VENDORRxBufferB0 & 0xff);
		} else {
			TXADDRH = ((int)VENDORRxBufferB1 >> 8);
			TXADDRL = ((int)VENDORRxBufferB1 & 0xff);
		}
		DMACON1bits.DMAEN = 1;
	} else if ((rr = VENDORRxReport(rxBuffer,
	    VENDOR_OUTPUT_INTR_BYTES)) != 0) {
		if(rxBuffer[0]==0){ /* PIC command */
			if (rr != sizeof(struct comm_command))
				return;
			if (RCMD->flags & FL_LED) {
				LED_PWM = RCMD->led_dim;
			} else {
				LED_PWM = 0;
			}
			if (RCMD->flags & FL_BACKLIGHT) {
				BACKLIGHT_PWM = RCMD->backlight_dim;
			} else {
				BACKLIGHT_PWM = 0;
			}
		} else {
			CS0 = 0;
			CD=COMMAND; /* LCD command */
			DMACON1 = 0x24; /* auto-inc, half duplex TX */
			DMACON2 = 0x00; /* 1 Tcy inter-byte delay */
			DMABCH = 0;
			DMABCL = (rr - 1);
			TXADDRH = ((int)rxBuffer >> 8);
			TXADDRL = ((int)rxBuffer & 0xff);
			DMACON1bits.DMAEN = 1;
		}

	}
}

void
main(void)
{
	static byte cdc_trf_state_l;
	softintrs = 0;
	rot_status.v = 0;
	rotary_pos = 0;
	buttons_status.v = 0;
	comm_status.rot_pos = 0;

	rotary_a = rotary_b = 0;
	button1 = button2 = button3 = button4 = buttonr = 0;

	counter_10hz = TIMER2_10HZ;
	counter_1hz = 10;

	stdout = STREAM_USART; /* Use the macro PUTCHAR with printf */

	INTCON2bits.RBPU = 1;
	ANCON0 = 0xf0; /* an0-an3 analog, an4-an7 digital */
	ANCON1 = 0x3f; /* an8-12 digital */

	LED_OUT = 0;
	TRISBbits.TRISB3 = 0;

	BACKLIGHT_OUT = 0;
	TRISBbits.TRISB2 = 0;

	/* switch PLL on */
	OSCTUNEbits.PLLEN = 1;

	/* configure sleep mode: PRI_IDLE */
	OSCCONbits.SCS = 0;
	OSCCONbits.IDLEN = 1;

	/* everything is low priority by default */
	IPR1 = 0;
	IPR2 = 0;
	IPR3 = 0;
	IPR4 = 0;
	IPR5 = 0;
	INTCON = 0;
	INTCON2 &= 0xf8;
	INTCON3 = 0;

	INTCONbits.GIE=0;
    	EECON2 = 0x55;
   	EECON2 = 0xAA;
    	EECON2 = 0x00; /* unlock PPS */

    	RPOR0= 11;	/* map RP0 pin to spi clock output */
   	RPOR1= 10;	/* map RP1 pin to spi  data out */
	RPINR22 = 0;	/* map SPI clock input to RP0 */
	RPOR5 = 14; /* CCP1 output */
	RPOR6 = 18; /* CCP2 output */

   	EECON2 = 0x55;
   	EECON2 = 0xAA;
   	EECON2 = 0x01; /* lock PPS */

	INTCONbits.GIE=1;

	PIR2bits.BCL1IF=0;
	CS0 = 0; /* chip select CS0B */
	LATAbits.LATA0 = 1; /* SPI clock idle */
	RST = 0;
	CD = 0;
        TRISAbits.TRISA7= 0; /* CS0 */
	TRISAbits.TRISA0= 0; /* clock */
	TRISAbits.TRISA1= 0; /* data */

	TRISAbits.TRISA6 = 0; /* CD */
        TRISAbits.TRISA3 = 0; /* RST */

	initSPI();    /* intilize spi connexion */
        initLCD();    /* intilize LCD  */

	RCONbits.IPEN=1; /* enable interrupt priority */

	/* configure timer0 as free-running counter at 46.875Khz */
	T0CON = 0x07; /* b00000111: internal clock, 1/256 prescaler */
	INTCONbits.TMR0IF = 0;
	INTCONbits.TMR0IE = 0; /* no interrupt */
	T0CONbits.TMR0ON = 1;

#if TIMER2_10HZ == 100
	/* configure timer2 for 1Khz interrupt */
	T2CON = 0x22; /* b00100010: postscaller 1/5, prescaler 1/16 */
	PR2 = 150; /* 1khz output */
#elif TIMER2_10HZ == 1000
	/* configure timer2 for 10Khz interrupt */
	T2CON = 0x22; /* b00100010: postscaller 1/5, prescaler 1/16 */
	PR2 = 15; /* 10khz output */
#elif TIMER2_10HZ == 2000
	/* configure timer2 for 20Khz interrupt */
	T2CON = 0x21; /* b00100001: postscaller 1/5, prescaler 1/4 */
	PR2 = 29; /* 20khz output */
#else
#error "unknown TIMER2_10HZ"
#endif
	T2CONbits.TMR2ON = 1;
	PIR1bits.TMR2IF = 0;
	IPR1bits.TMR2IP = 1; /* high priority interrupt */
	PIE1bits.TMR2IE = 1;

	/* configure timer4 for for PWM, about 600Khz */
	T4CON = 0x02; /* b00000010: prescaler 1/16 */
	PR4 = 100; /* about 7.5Khz */
	PIE3bits.TMR4IE = 0;
	T4CONbits.TMR4ON = 1;

	/* setup ECCP1 (backlight) and ECCP2 (LED) in PWM mode */
	CCP1CON = 0x0c; /* PWM mode */
	CCP2CON = 0x0c;
	CCPTMRS0 = 0x09; /* CCP1 and CCP2 use timer4 */
	PSTR1CON = 0x01; /* output A */
	PSTR2CON = 0x01;
	CCPR1L = 0;
	CCPR2L = 0;

	/* configure UART for 57600Bps at 48Mhz */
	SPBRG2 = 12;

	/* init TX buffer pointers */
	uart_txbuf_cons = uart_txbuf_prod = 0;

	INTCONbits.GIE_GIEH=1;  /* enable high-priority interrupts */
	INTCONbits.PEIE_GIEL=1; /* enable low-priority interrrupts */
	TRISBbits.TRISB4 = 1;
	TRISBbits.TRISB5 = 1;
	TRISA = 0x04; 		/*set all digital I/O to inputs */
	TRISAbits.TRISA2 = 1; /*Disable the output driver for pin RA2/AN2  */

	ADCON0bits.VCFG = 0; /*Vdd is the +ve reference  */
	ADCON1bits.ADCS = 0b001; /*Fosc/8 is the conversion clock */
	ADCON0bits.CHS = 2; /*select analog input, AN2  */
	ADCON0bits.ADON = 1; /*Turn on the ADC */

	/* enable watch dog timer */
	WDTCON = 0x01;

#include "version.h"
	fprintf(STREAM_USER, "\nedisplay v%x.%x", REV_MAJOR, REV_MINOR);
	fprintf(STREAM_USER, BUILD);
#undef BUILD
	flushtx();

	/* initialize USB */
	UCFG = _UPUEN| _FSEN | 0 /* MODE_PP */;
	deviceState = DETACHED;
	remoteWakeup = 0x00;
	currentConfiguration = 0x00;
	LED_PWM = 100;

	while(1) {
		__asm__("clrwdt");

		while (PIR3bits.RC2IF) { /* a char is ready on serial */
			process_char(RCREG2);
			if (RCSTA2bits.OERR) {
			    RCSTA2bits.CREN = 0;
			    RCSTA2bits.CREN = 1;
			}
		}
		EnableUSBModule();  /* enable usb  */
		/* As long as we aren't in test mode (UTEYE), process */
	       /* USB transactions. */
		if(UCFGbits.UTEYE == 0)
			ProcessUSBTransactions();
		/* Application specific tasks      */

		if ((deviceState >= CONFIGURED) && (UCONbits.SUSPND==0))
		{
			if (DMACON1bits.DMAEN == 0) {
				checkrx();
			}
			if (softintrs & INT_ST_CH) {
				INTCONbits.GIE_GIEH=0;  /* disable interrupts */
				comm_status.buttons = buttons_status.v;
				comm_status.rot_pos += rotary_pos;
				rotary_pos = 0;
				INTCONbits.GIE_GIEH=1;  /* enable interrupts */
				if (VENDORTxReport((byte *)&comm_status,
				    sizeof(comm_status)) == sizeof(comm_status)) {
					comm_status.rot_pos = 0;
					softintrs &= ~INT_ST_CH;
				}
			}
		}
		/*__asm__("sleep"); */
	}
}


/** V E C T O R  R E M A P P I N G *******************************************/

/*extern void _startup (void);        // See c018i.c in your C18 compiler dir */

void _reset (void) __naked __interrupt 0
{
	__asm__("goto __startup");
}

void _startup (void) __naked
{
	__asm
	/* Initialize the stack pointer */
	lfsr 1, _stack_end
	lfsr 2, _stack_end
	clrf _TBLPTRU, 0    /* 1st silicon doesn't do this on POR */

	/*
	 * initialize the flash memory access configuration. this is harmless
	 * for non-flash devices, so we do it on all parts.
	 */
	bsf _EECON1, 7, 0
	bcf _EECON1, 6, 0
	__endasm ;

	/* Call the user's main routine */
	main();

	__asm__("reset");
}

/*
 * high priority interrupt. Split in 2 parts; one for the entry point
 * where we'll deal with timer0, then jump to another address
 * as we don't have enough space before the low priority vector
 */
void _irqh (void) __naked __shadowregs __interrupt 1
{
	__asm
	bcf   _PIR1, 1
	goto _irqh_timer2
	__endasm ;

}

void irqh_timer2(void) __naked
{
	/*
	 * no sdcc registers are automatically saved,
	 * so we have to be carefull with C code !
	 */
	__asm
	MOVFF   r0x00, POSTDEC1
	__endasm;
	counter_10hz--;
	if (counter_10hz == 0) {
		counter_10hz = TIMER2_10HZ;
		softintrs |= INT_10HZ;
	}
	rotary_a = rotary_a << 1;
	if (ROTARY_A)
		rotary_a |= (unsigned char)1;
	rotary_b = rotary_b << 1;
	if (ROTARY_B)
		rotary_b |= (unsigned char)1;
	rotary_a &= 0xf;
	rotary_b &= 0xf;
	if (rotary_a == 0xf) {
		if (!rot_status.s.rotary_a) { /* rising edge on A */
			if (rot_status.s.pending_b) {
				/* already got rising edge on B */
				rotary_pos -= (signed char)1;
				softintrs |= INT_ST_CH;
				rot_status.s.pending_b = 0;
			} else {
				rot_status.s.pending_a = 1;
			}
		}
		rot_status.s.rotary_a = 1;
	} else if (rotary_a == 0) {
		rot_status.s.rotary_a = 0;
		rot_status.s.pending_a = 0;
	}
	if (rotary_b == 0xf) {
		if (!rot_status.s.rotary_b) { /* rising edge on B */
			if (rot_status.s.pending_a) {
				/* already got rising edge on A */
				rotary_pos += (signed char)1;
				softintrs |= INT_ST_CH;
				rot_status.s.pending_a = 0;
			} else {
				rot_status.s.pending_b = 1;
			}
		}
		rot_status.s.rotary_b = 1;
	} else if (rotary_b == 0) {
		rot_status.s.rotary_b = 0;
		rot_status.s.pending_b = 0;
	}
	if (PIE1bits.ADIE == 0) {
		PIE1bits.ADIE = 1;
		ADCON0bits.GO = 1;
	}

	__asm
	MOVFF   PREINC1, r0x00
	retfie 1
	nop
	__endasm;
}

void _irq (void) __interrupt 2 /* low priority */
{
	if (PIE1bits.ADIE && PIR1bits.ADIF) {
		/* A/D values:
		 * ADRH = 256 / Vcc * V
		 * V = Vcc * R / (R + 10k)
		 * so
		 * ADR = 256 * R / (R + 10k)            
		 * for our buttons this gives us:
		 * 0
		 * 42
		 * 85 
		 * 128
		 * 170
		 */

		ad_result = ADRESH;
		PIE1bits.ADIE = 0;
		button1 = button1 << 1;
		button2 = button2 << 1;
		button3 = button3 << 1;
		button4 = button4 << 1;
		buttonr = buttonr << 1;
		if(ad_result < 212 && ad_result > 149)
			button1 |= (char)1;
		else if(ad_result < 149 && ad_result > 106)
			button2 |= (char)1;
		else if(ad_result < 106 && ad_result > 63)
			button3 |= (char)1;
		else if(ad_result < 63 && ad_result > 21)
			button4 |= (char)1;
		else if(ad_result < 21)
			buttonr |= (char)1;
		if (button1 == 0xff && buttons_status.s.b1 == 0) {
			buttons_status.s.b1 = 1;
			softintrs |= INT_ST_CH;
		} else if (button1 == 0x00 && buttons_status.s.b1 == 1) {
			buttons_status.s.b1 = 0;
			softintrs |= INT_ST_CH;
		}
		if (button2 == 0xff && buttons_status.s.b2 == 0) {
			buttons_status.s.b2 = 1;
			softintrs |= INT_ST_CH;
		} else if (button2 == 0x00 && buttons_status.s.b2 == 1) {
			buttons_status.s.b2 = 0;
			softintrs |= INT_ST_CH;
		}
		if (button3 == 0xff && buttons_status.s.b3 == 0) {
			buttons_status.s.b3 = 1;
			softintrs |= INT_ST_CH;
		} else if (button3 == 0x00 && buttons_status.s.b3 == 1) {
			buttons_status.s.b3 = 0;
			softintrs |= INT_ST_CH;
		}
		if (button4 == 0xff && buttons_status.s.b4 == 0) {
			buttons_status.s.b4 = 1;
			softintrs |= INT_ST_CH;
		} else if (button4 == 0x00 && buttons_status.s.b4 == 1) {
			buttons_status.s.b4 = 0;
			softintrs |= INT_ST_CH;
		}
		if (buttonr == 0xff && buttons_status.s.br == 0) {
			buttons_status.s.br = 1;
			softintrs |= INT_ST_CH;
		} else if (buttonr == 0x00 && buttons_status.s.br == 1) {
			buttons_status.s.br = 0;
			softintrs |= INT_ST_CH;
		}
		PIE1bits.ADIE = 0;
	}
	if (PIE3bits.TX2IE && PIR3bits.TX2IF) {
		if (uart_txbuf_prod == uart_txbuf_cons) {
			PIE3bits.TX2IE = 0; /* buffer empty */
		} else {
			/* Place char in TXREG - this starts transmition */
			TXREG2 = uart_txbuf[uart_txbuf_cons];
			uart_txbuf_cons = (uart_txbuf_cons + 1) & UART_BUFSIZE_MASK;
		}
	}
}

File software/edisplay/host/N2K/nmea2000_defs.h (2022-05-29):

/*
 * Copyright (c) 2019 Manuel Bouyer
 *
 * All rights reserved.
 *
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
 * THIS SOFTWARE IS PROVIDED BY THE NETBSD FOUNDATION, INC. AND CONTRIBUTORS
 * ``AS IS'' AND ANY EXPRESS OR IMPLIED WARRANTIES, INCLUDING, BUT NOT LIMITED
 * TO, THE IMPLIED WARRANTIES OF MERCHANTABILITY AND FITNESS FOR A PARTICULAR
 * PURPOSE ARE DISCLAIMED.  IN NO EVENT SHALL THE FOUNDATION OR CONTRIBUTORS
 * BE LIABLE FOR ANY DIRECT, INDIRECT, INCIDENTAL, SPECIAL, EXEMPLARY, OR
 * CONSEQUENTIAL DAMAGES (INCLUDING, BUT NOT LIMITED TO, PROCUREMENT OF
 * SUBSTITUTE GOODS OR SERVICES; LOSS OF USE, DATA, OR PROFITS; OR BUSINESS
 * INTERRUPTION) HOWEVER CAUSED AND ON ANY THEORY OF LIABILITY, WHETHER IN
 * CONTRACT, STRICT LIABILITY, OR TORT (INCLUDING NEGLIGENCE OR OTHERWISE)
 * ARISING IN ANY WAY OUT OF THE USE OF THIS SOFTWARE, EVEN IF ADVISED OF THE
 * POSSIBILITY OF SUCH DAMAGE.
 */

#ifndef NMEA2000_DEFS_H_
#define NMEA2000_DEFS_H_

class nmea2000_desc {
    public:
        const char *descr;
	const bool isuser;
	const int pgn;
	bool enabled;

	inline nmea2000_desc(const char *desc, bool isuser, int pgn) :
	    descr(desc), isuser(isuser), pgn(pgn) {enabled = false;}
	virtual ~nmea2000_desc() {};
};

#define NMEA2000_PRIORITY_HIGH          0
#define NMEA2000_PRIORITY_SECURITY      1
#define NMEA2000_PRIORITY_CONTROL       3
#define NMEA2000_PRIORITY_REQUEST       6
#define NMEA2000_PRIORITY_INFO          6
#define NMEA2000_PRIORITY_ACK           6
#define NMEA2000_PRIORITY_LOW           7

#define NMEA2000_ADDR_GLOBAL    255
#define NMEA2000_ADDR_NULL      254
#define NMEA2000_ADDR_MAX       251

#define NMEA2000_INDUSTRY_GROUP 4

#define ISO_ADDRESS_CLAIM	60928U
#define ISO_REQUEST		59904U

#define NMEA2000_DATETIME	129033U
#define NMEA2000_ATTITUDE	127257U
#define NMEA2000_RATEOFTURN	127251U
#define NMEA2000_COGSOG		129026U
#define NMEA2000_XTE		129283U
#define NMEA2000_NAVDATA	129284U
#define NMEA2000_ENV_PARAM	130311U 
#define NMEA2000_WIND_DATA	130306U

#define PRIVATE_COMMAND_STATUS	61846U
#define 	HEADING_INVALID 32767
#define PRIVATE_COMMAND_ACUATOR	38400U
#define PRIVATE_COMMAND_ENGAGE	38656U
#define PRIVATE_COMMAND_ERRACK	38912U
#define PRIVATE_COMMAND_FACTORS	39168UL
#define PRIVATE_COMMAND_FACTORS_REQUEST	39424U
#define PRIVATE_REMOTE_CONTROL	39680U
#define 	CONTROL_MOB     0x00
#define 	CONTROL_MOB_MARK        0x00
#define 	CONTROL_MOB_SIZE 2
#define 	CONTROL_LIGHT   0x01
#define 	CONTROL_LIGHT_OFF       0x00
#define 	CONTROL_LIGHT_ON        0x01
#define 	CONTROL_LIGHT_VAL       0x02  
#define 	CONTROL_LIGHT_REV       0x03
#define 	CONTROL_LIGHT_SIZE     2      
#define 	CONTROL_LIGHT_VAL_SIZE 3      
#define 	CONTROL_RESET   0x02
#define 	CONTROL_RESET_SIZE 1
#define 	CONTROL_MUTE    0x02
#define 	CONTROL_MUTE_SIZE 2
#define 	CONTROL_BEEP    0x04
#define 	CONTROL_BEEP_SHORT      0x00  
#define 	CONTROL_BEEP_LONG       0x01  
#define 	CONTROL_BEEP_SIZE 2
#define 	CONTROL_REMOTE_RADIO    0x05  
#define		CONTROL_REMOTE_RADIO_SIZE 5
#define		CONTROL_REMOTE_DISPLAY  0x06
#define		CONTROL_REMOTE_DISPLAY_PAGE     0x00
#define		CONTROL_REMOTE_DISPLAY_PAGE_SIZE 3

inline double rad2deg(int rad)
{
	double deg;
	deg = (double)rad / 174.53293F;
	if (deg < 0)
		deg += 360.0F;
	return deg;
}

inline double urad2deg(unsigned int rad)
{
	double deg;
	deg = (double)rad / 174.53293F;
	return deg;
}

inline int deg2rad(double deg)
{
        double rad;

	if (deg > 180)
		deg -= 360;

	rad = deg * 174.53293F;
	return (int)(rad + 0.5);
}

inline unsigned int udeg2rad(double deg)
{
        double rad;

	rad = deg * 174.53293F;
	return (unsigned int)(rad + 0.5);
}

#endif

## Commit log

2016-03-17 Add hardware schematics and PCB
    [Audio.sch, buttons-board.kicad_pcb, buttons-board.sch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]
2016-03-18 Add metadata information to sheets Add pdf for the schematics
    [buttons-board.kicad_pcb, buttons-board.sch, connect_board.kicad_pcb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]
2016-03-19 Swap D and S of Q503 (oups)
    [marine_gps.kicad_pcb, marine_gps.sch, marine_gps_audio.sch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]
2016-03-19 Rename machine_gps_can to marine_gps_can (typo)
    [marine_gps.sch, marine_gps_audio.sch, marine_gps_can.sch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]
2016-04-28 Add software-related bits: configuration, firmware for the pic18 and associated i2c driver for the NetBSD side.
2016-04-29 Add photos of the PCBs
2016-05-30 Add a C program to switch the GPS module to 4800 bauds.
2018-04-03 Add a interrupt bit in the status register interrupt also on key release event bump version
2018-04-03 Handle FDT-based config Because of the lack of mask/unmask in FDT kernels, switch to edge-triggered irq Use the interrupt bit in status request at last rev 0x11 for power button handling
2018-04-03 Switch to fdt-based SUNXI kernel. Add the associated dts config.
2019-01-11 Add new edisplay PCB module, an USB-connected external LCD display.
    [edisplay.kicad_pcb, edisplay.sch, edisplay_buttons.sch]
2019-03-15 Add design file for the front PMMA screen
    [LCD_screen.dxf]
2019-03-15 Fix mode
    [LCD_screen.dxf]
2019-06-26 SPI bug fixes and optimisations
    [main.c]
2019-06-27 More DMA use use dual buffer for bulk input bump bulk size to the max (64)
2019-12-09 Move prevous code under demo/, and import lvgl-based interface, Handle some navigation data from canbus at this time (sill WIP). Handle only PC driver at this time.
2019-12-10 Restructure for upcoming USB edisplay drivers
2019-12-10 drivers for the USB edisplay. Untested.
2019-12-11 No need for driver includes here.
2019-12-11 Fix signed/unsigned issue really report buttons state, not just click events
2019-12-11 Some cleanups, helps with fast hosts. We may need interrupts for USB processing in the future.
2019-12-11 Correct UC1610 initialisation Close and restart USB connection on any error; we don't get specific error when the device is disconnected On USB init send LV_EVENT_REFRESH to the top layer.
    [edisplay.c]
2019-12-12 Don't flood stderr when the USB device is disconnected. Fix NULL deref if the USB device is connected before app is started.
    [edisplay.c]
2019-12-12 Add a com_command structure for sending commands to the PIC. Implement backlight control, and switch LED control to PWM.
2019-12-12 Use pic/comms.h for commands sent to, and status from the PIC Implement backlight control. Dimm the LED when backlight it on
2020-02-06 Add some qcad files from edisplay design
    [cover-wp11.scad, panel-cut.dxf, wp11+dogxl160-codeur.dxf]
2020-02-06 Add defines for buttons
2020-02-06 print key value for LV_EVENT_KEY
2020-02-09 focus/unfocus individual pages instead of the top level object for encoder. Implement page button
2020-02-09 Fix page cycle handling Add empty callback for group focus/edit style, we don't want style changes on the page obj.
    [edisplay.c]
2020-02-13 work in progres on autopilot and control frames implementation
2020-02-13 Set the dst address of control frames per frame. Move dst address handling for autopilot frames to nmea2000_autopilot_tx
2020-02-13 Fix autopilot heading display
    [edisplay.c]
2020-02-13 Also display param slot
2020-02-15 Factor out transient list creations. Add list selection of param slot for autopilot
2020-03-09 Adjust base depth Fix warning message
    [cover-wp11.scad]
2020-03-14 Fix place of conges()
    [cover-wp11.scad]
2020-03-21 Send change slot commands. Fix key handlings
2020-03-21 switch to event-based update system and get rid of display lock.
2020-03-21 We can't send event without mutex in multithreaded apps (sigh). So just write values to memory in the n2k rx thread, and update display in the main one.
2020-03-21 Implement requesting slot factors
2020-03-24 Allow more transient pages: add a epage_is_transient entry to edisp_page_t, and test this instead of handling only the epage_retro case. Add work in progress on pilot params edit
2020-03-26 Add a new widget, lv_eslider, derived from lv_slider, more usefull for rotating knobs. It display its value in text, doesn't show the knob, and allows different step values.
    [edisplay.c]
2020-03-28 Allow editing PID factors
2020-03-28 When autopilot is in standby, switch to off on cancel event.
2020-04-26 When a route is activated, or we switch to a new waypoint, switch to the navigation page.
